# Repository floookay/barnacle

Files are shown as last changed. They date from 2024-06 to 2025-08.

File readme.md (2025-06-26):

# barnacle

The barnacle is unibody ortho keyboard with an Alice-like split on the pinky columns, a fixed layout that's compatible with keycap base kits and a modular middle piece.

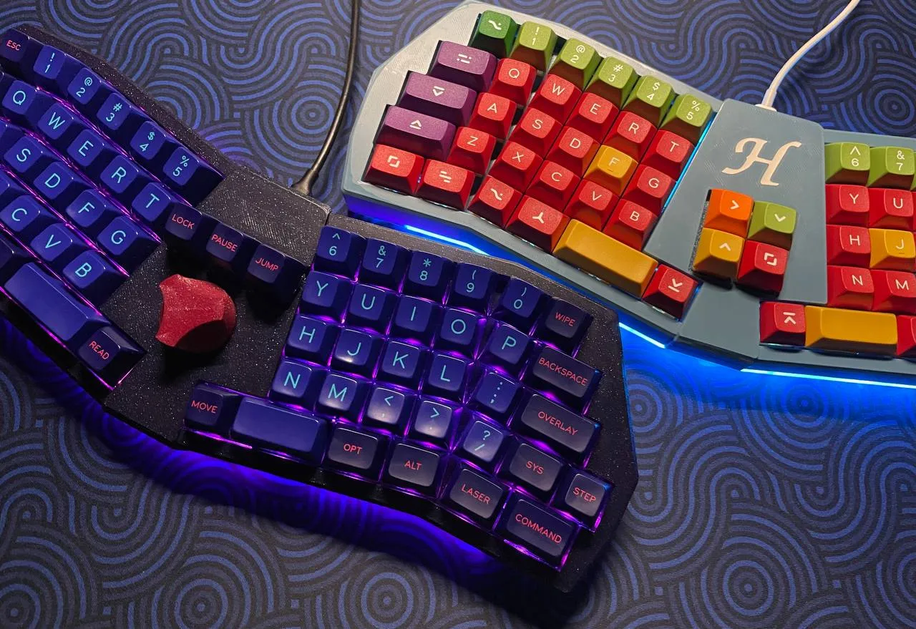
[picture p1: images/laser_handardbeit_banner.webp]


## inspiration

I love the look of the boardrun classic and desperately wanted to get one myself but things happend so that's not likely anymore unfortunately.  
The creativity of designers with colorful keycap designs and interesting keyboard designs got me hooked with the hobby. I bought a bunch of keycap sets over the years that I don't use anymore since I switched to ortho/colstagger keyboards a couple of years ago, because the different asymmetrical key sizes of standard keyboards make it difficult. I don't like the layout or the asthetics of most keyboard designs that are trying to work around this issue. That's why I created the barnacle.

## design goals

- 5x6 unibody ortho keyboard
- base kit compatibility
- 3d printable on 220mm build plates
- symmetric design (amap)
- outer thumb keys next to space bars
- easily expandable later on
- no stabilizers

## layout

The main layout you use to type is fixed but the different cores offer some variety. The default keymap is based on my Sol 3 keymap but you can modify it in QMK of course.

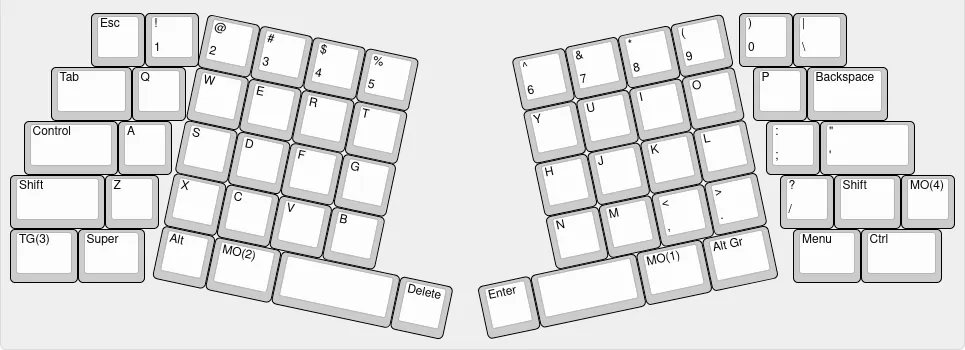
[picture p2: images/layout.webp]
layout


The base layout is pretty much compatible with every base kit. These are the keys you could look out for beforehand as they are sometimes missing:
- a second R3 1.75u key (capslock/control)
- if ISO is omitted and the bottom row is another profile than the row above: a 1.25u shift key. If they are the same profile you can use the 7th 1.25u mod key
- 2u and 2.25u space bars, alternativly you can use shift keys

> [!TIP]
> Some 40s kits have accent colored R3 1.75u enter keys so thats something you could look out for if you like accent keys.

## pcb

The barnacle uses a two part pcb design which are connected via hotswap sockets:  
- shell pcb
- core pcb in different variations

It uses the [0xCB Helios](https://keeb.supply/products/0xcb-helios) as its controller. It's an affordable open-source pro-micro-compatible RP2040 controller with ESD protection and additional pins and features.

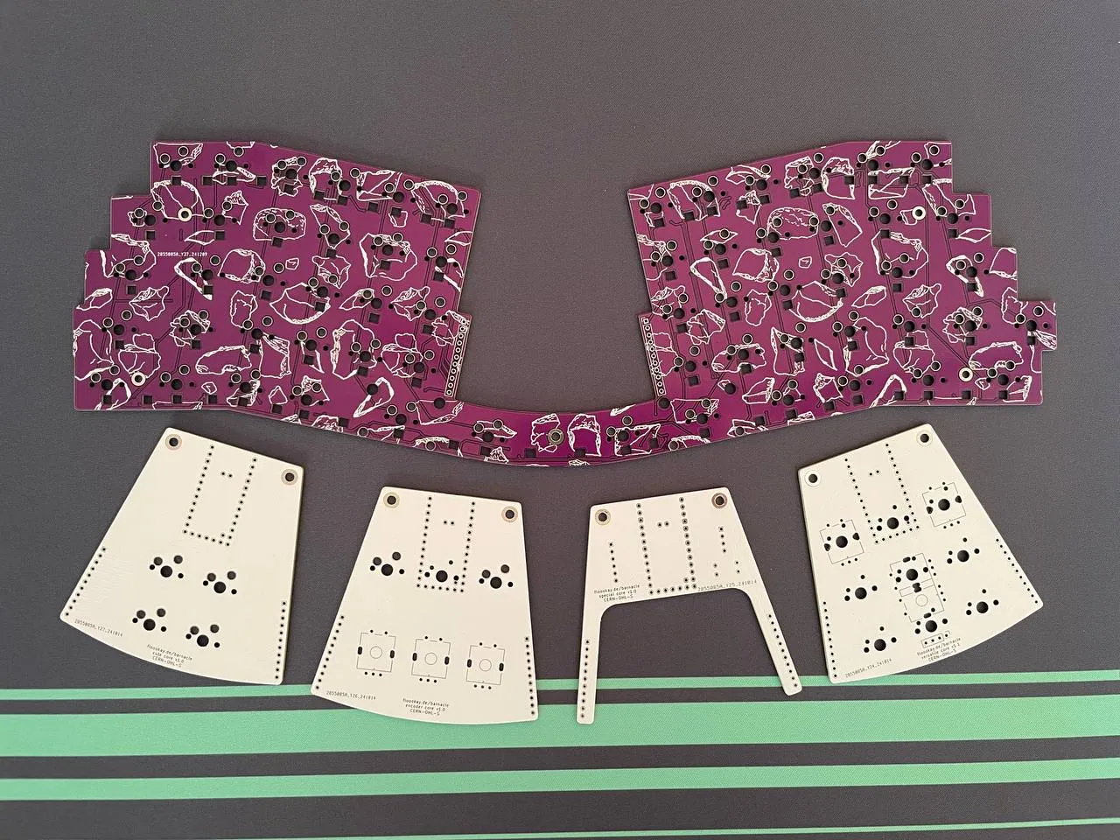
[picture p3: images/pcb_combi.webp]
pcb


> [!NOTE]
> See [pcb readme](./pcb/readme.md) for detailed information about the pcb design.

## case

- 3mm acrylic bottom
- 5 degree typing angle
- designed for 3d printing
- sandwich mount
- exchangable core pieces

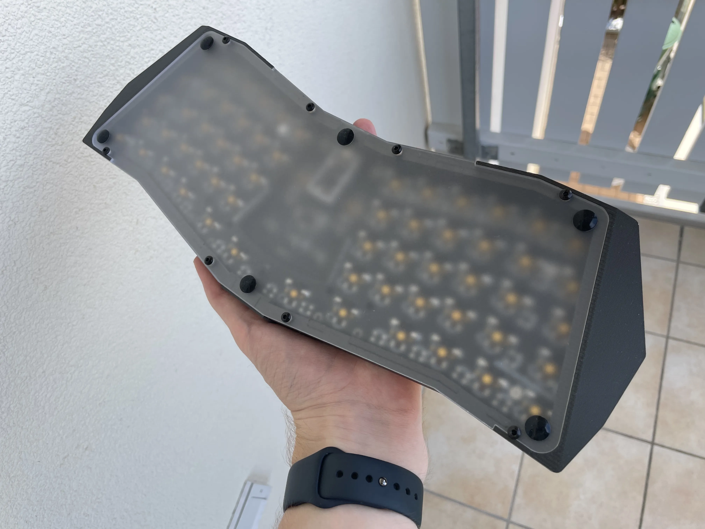
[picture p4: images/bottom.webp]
bottom

<details>
<summary>side and back pictures</summary>

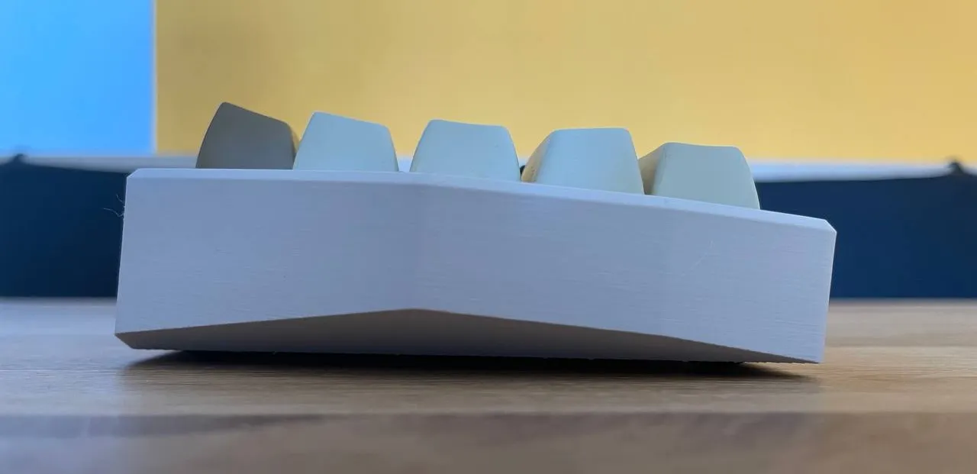
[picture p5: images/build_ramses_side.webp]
side profile

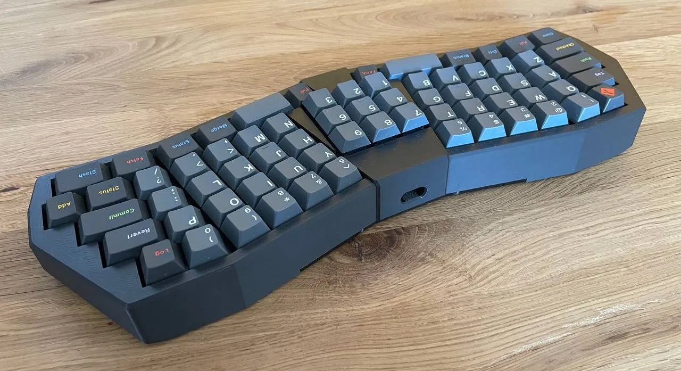
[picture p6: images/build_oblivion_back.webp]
backside

</details>

> [!NOTE]
> See [case readme](./case/readme.md) for detailed information about the case design.

## firmware

This keyboard is powered by QMK: <https://github.com/floookay/qmk_firmware/tree/barnacle/keyboards/barnacle> (not yet in main branch)

I also uploaded a firmware for vial as well as the json in the firmware folder.

## bom and assembly

For the bill of materials and assembly instructions see [here](./build_guide.md).

## pictures

<details>
<summary>encoder core, SA Ramses, Novelkeys x Kailh Cream, printed with AzureFilm PLA Matte Off-White</summary>

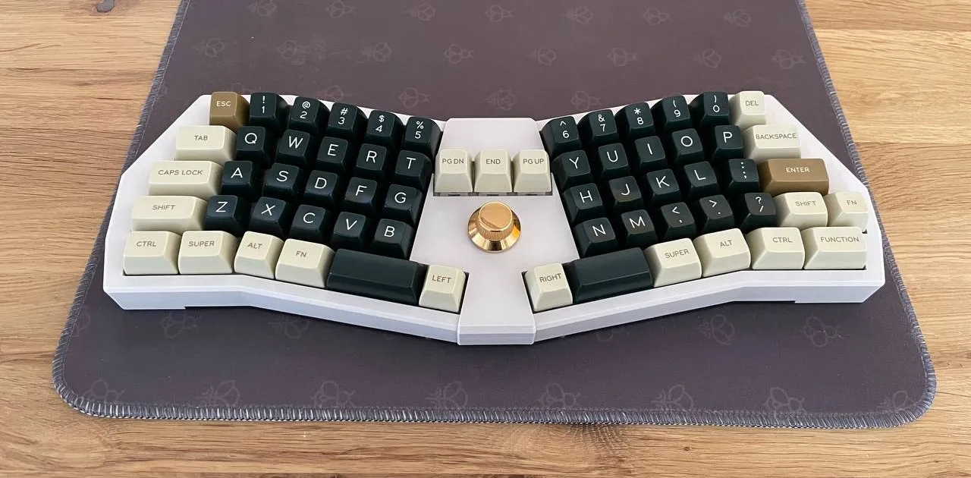
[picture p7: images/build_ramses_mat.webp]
  
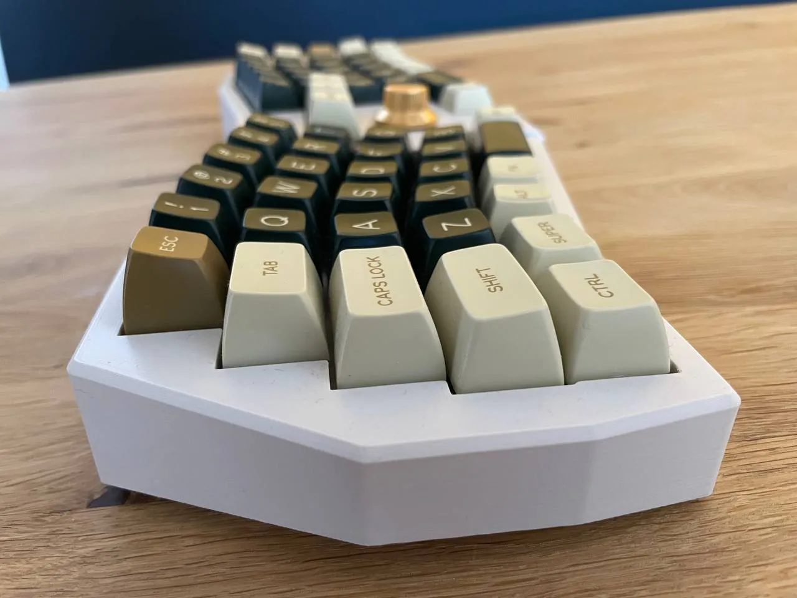
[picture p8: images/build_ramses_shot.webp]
  
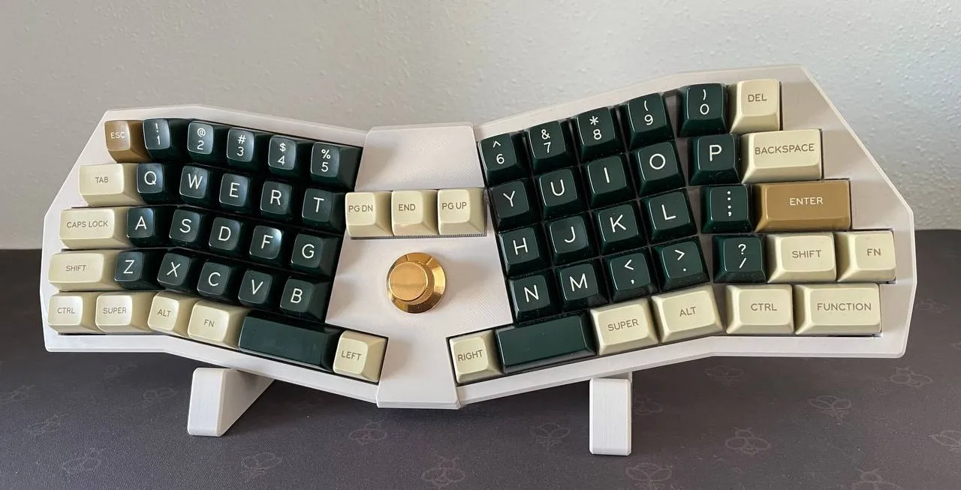
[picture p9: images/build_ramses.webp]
  
</details>

<details>
<summary>cute core, DSS Handarbeit, Gateron EF Curry, printed with RecylingFabrik rPLA flaches Gewässer</summary>

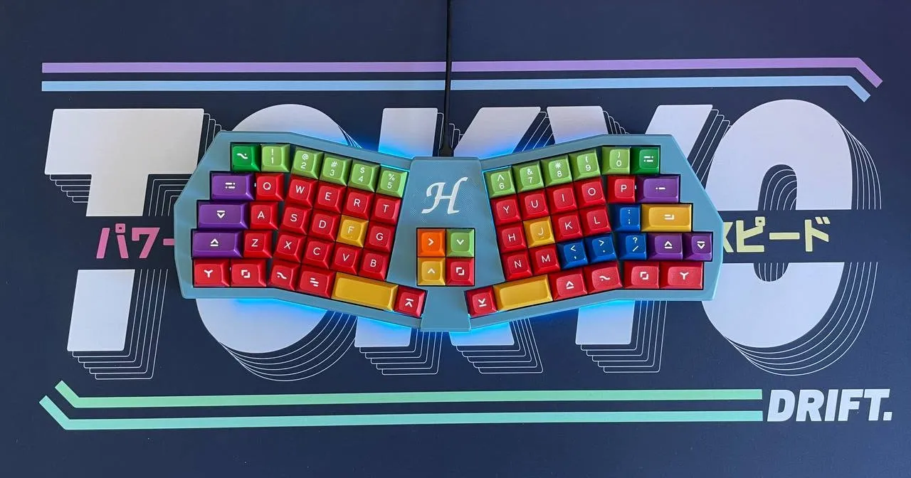
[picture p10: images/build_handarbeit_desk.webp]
  
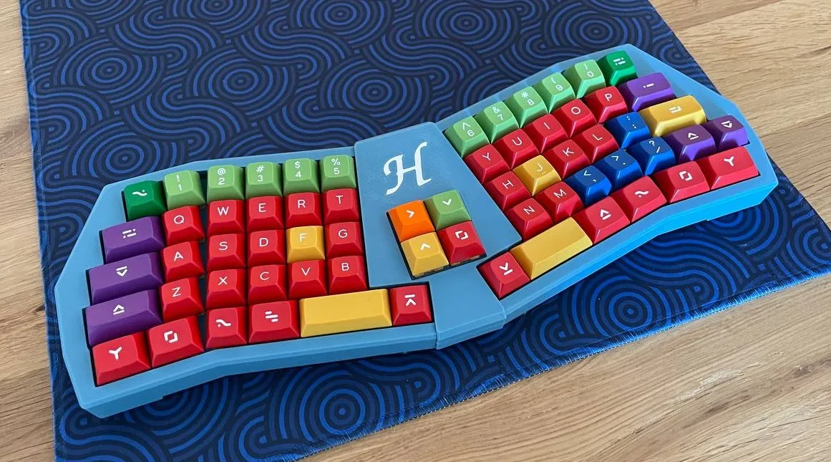
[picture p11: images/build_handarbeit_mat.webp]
  
</details>

<details>
<summary>versatile core with a 1.3" oled screen, GMK Dracula, Gateron Black Silent Inks, printed with Prusament PLA Galaxy Black</summary>

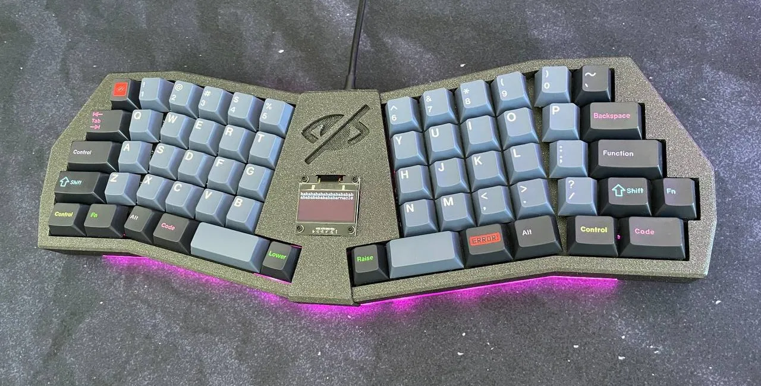
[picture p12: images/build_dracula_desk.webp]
  
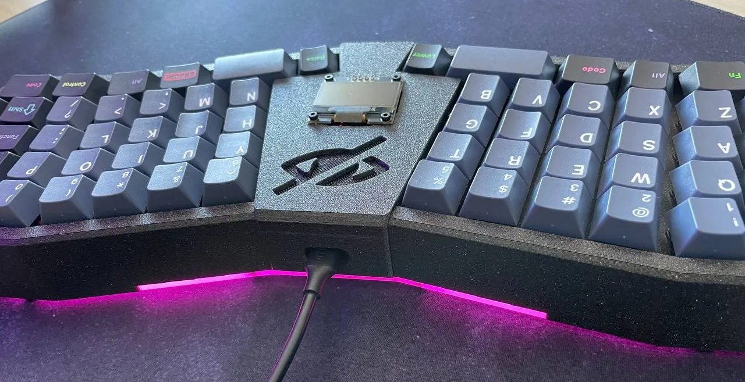
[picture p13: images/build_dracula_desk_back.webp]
  
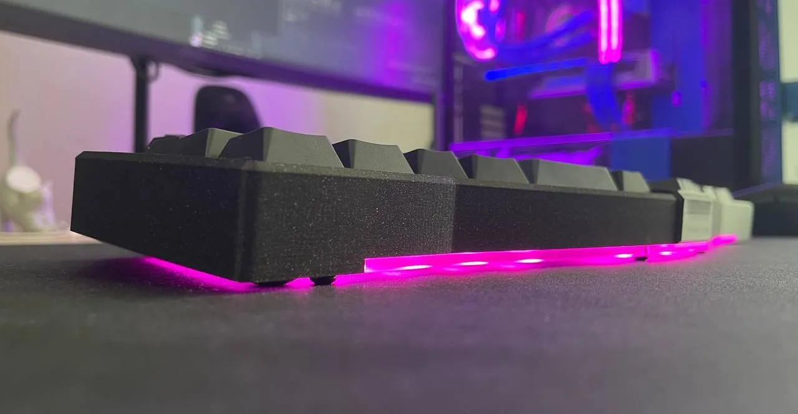
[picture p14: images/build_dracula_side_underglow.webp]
  
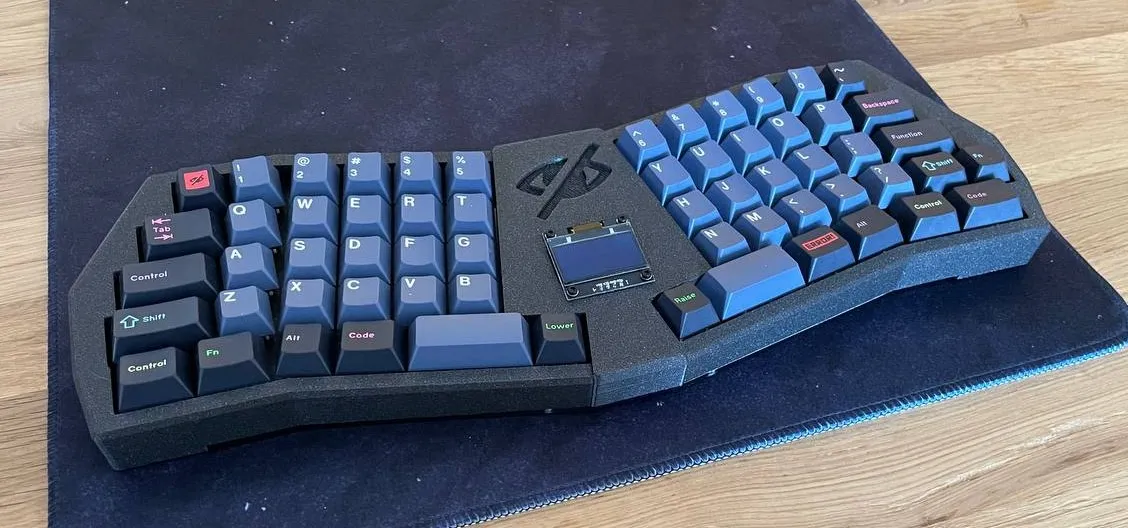
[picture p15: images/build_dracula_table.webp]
  
</details>

<details>
<summary>versatile core encoder, MT3 Serika, Trash Linears, printed with Sunlu PLA Black matte</summary>

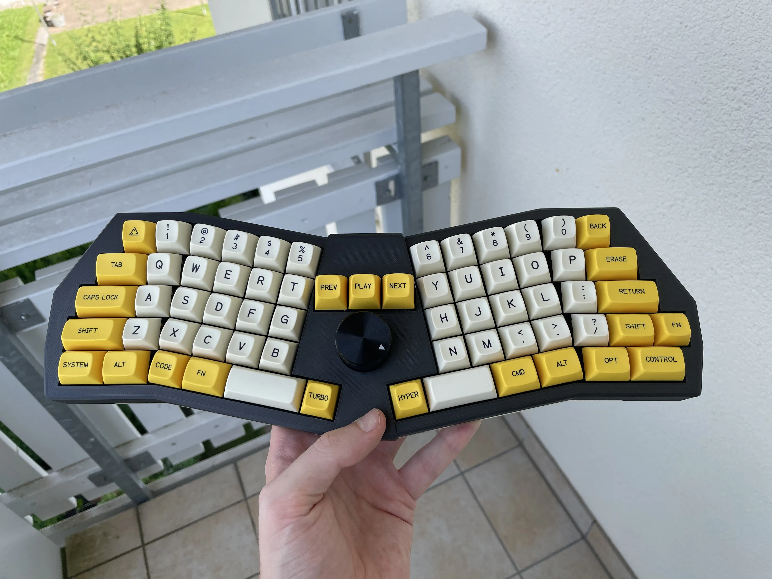
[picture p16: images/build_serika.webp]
  
</details>

<details>
<summary>encoder core, SA Laser, Gateron Black Silent Inks, printed with Polymaker PolyLite PLA Galaxy Dark Blue</summary>

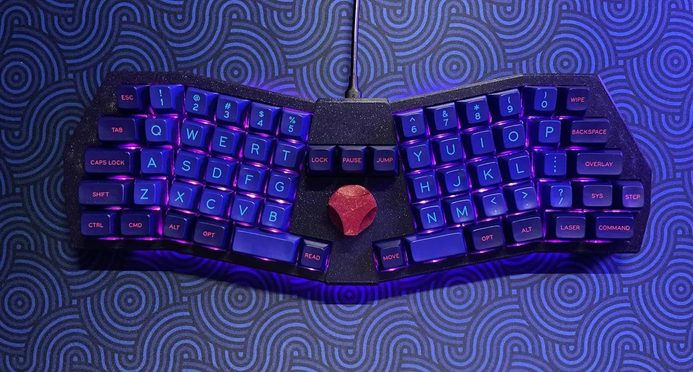
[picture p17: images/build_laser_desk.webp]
  
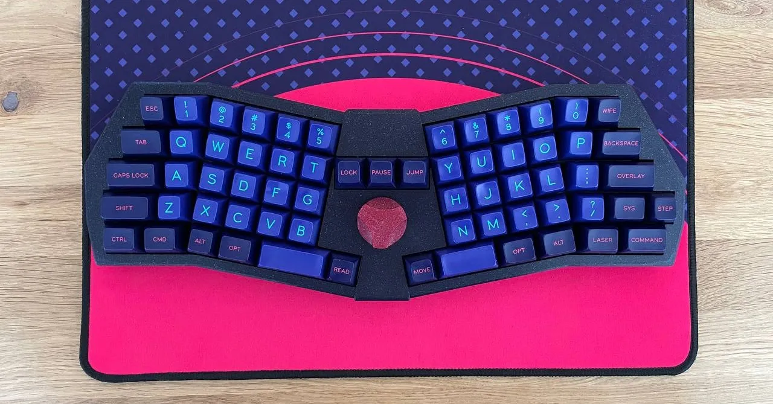
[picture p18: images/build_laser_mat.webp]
  
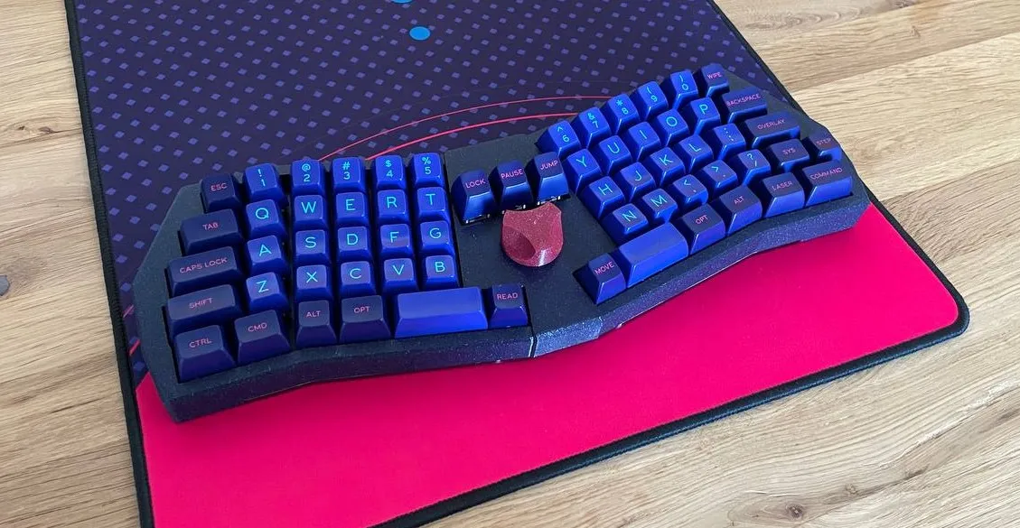
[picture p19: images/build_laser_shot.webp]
  
</details>

<details>
<summary>versatile core, GMK Foundation, MMD Holy Panda, printed with AzureFilm PLA Matte Off-White</summary>

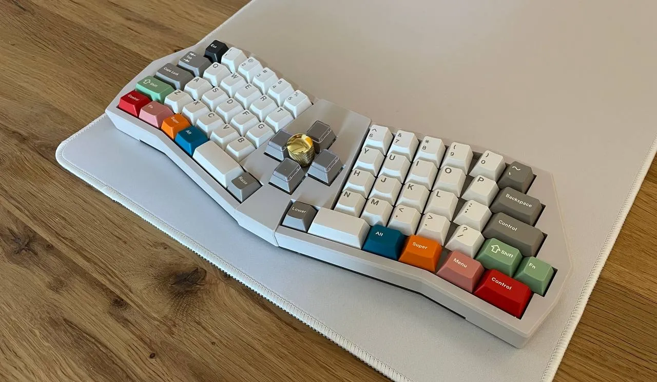
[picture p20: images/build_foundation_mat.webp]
  
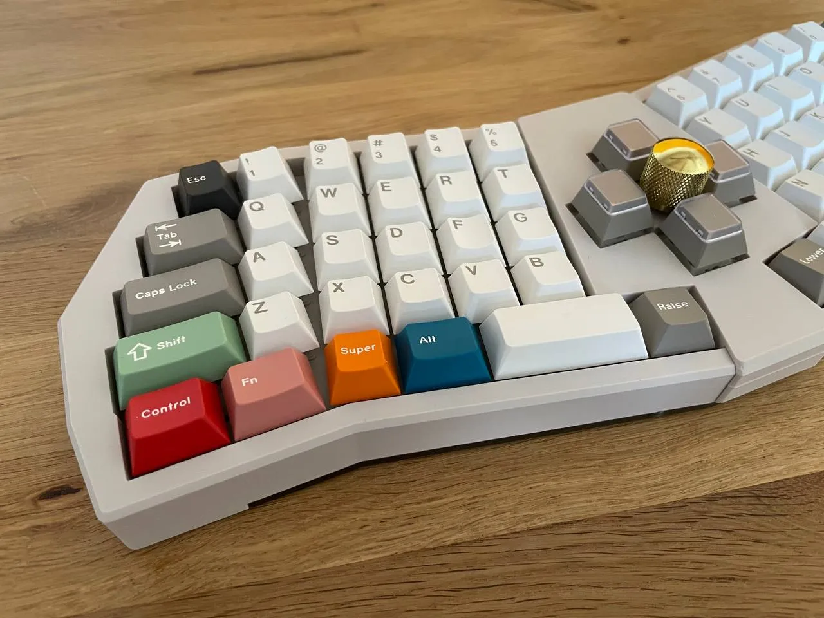
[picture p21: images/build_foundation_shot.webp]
  
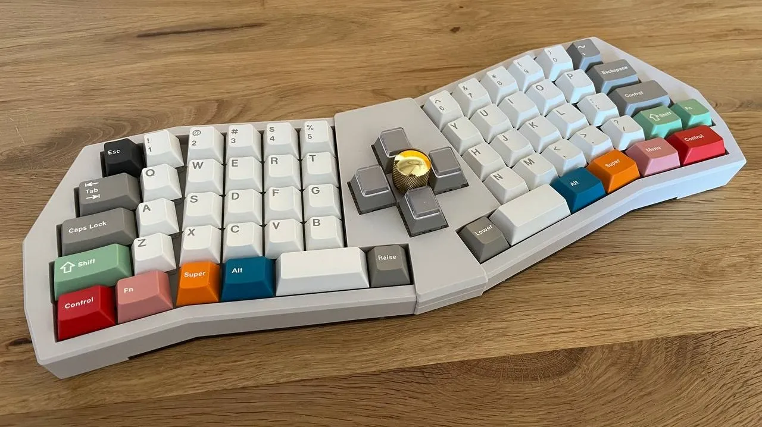
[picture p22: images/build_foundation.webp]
  
</details>

<details>
<summary>versatile core numpad, GMK Oblivion, Gateron 8008 Inks, printed with RecylingFabrik rPLA Schimmernde Nacht</summary>

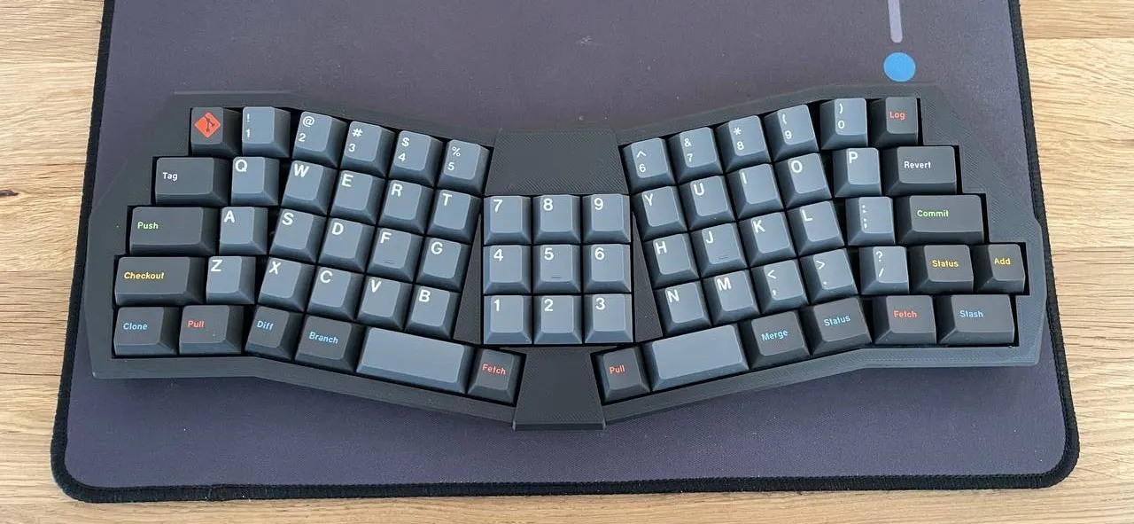
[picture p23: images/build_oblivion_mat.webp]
  
barnacle  
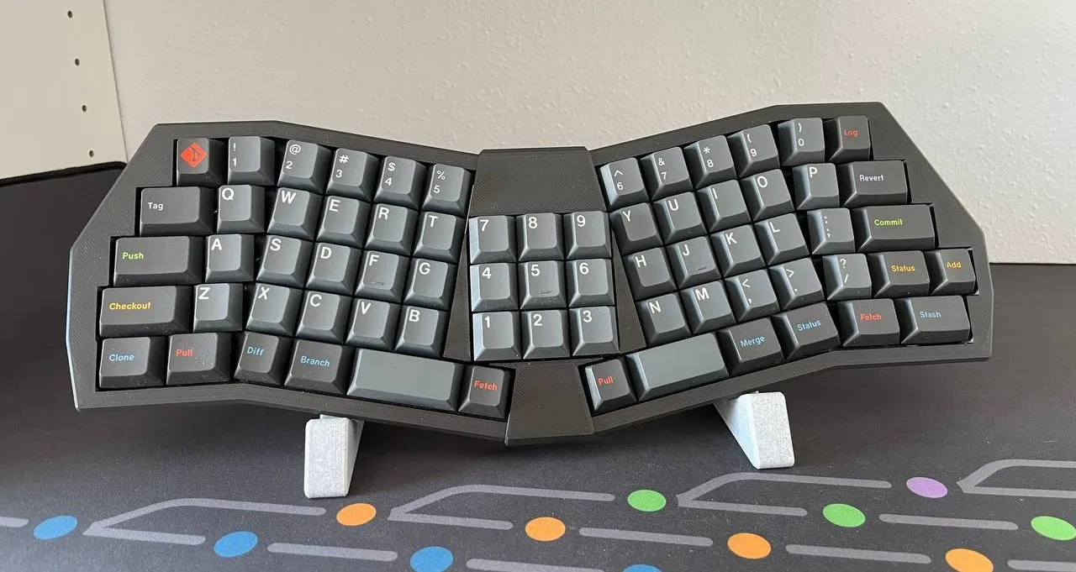
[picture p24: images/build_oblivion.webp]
  
</details>

## acknowledgements

Huge thank you to ebastler and MarvFPV for the awesome [marbastlib](https://github.com/ebastler/marbastlib) library for KiCAD as well as the ClackTales community for their support.

Thanks for reading and feel free to reach out to me or create issues or PRs if you have any questions or things to improve upon.

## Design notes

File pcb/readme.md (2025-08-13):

# pcb

## shell pcb

The shell has a fixed layout with hotswap sockets as well as RGB underglow und per key RBG leds.

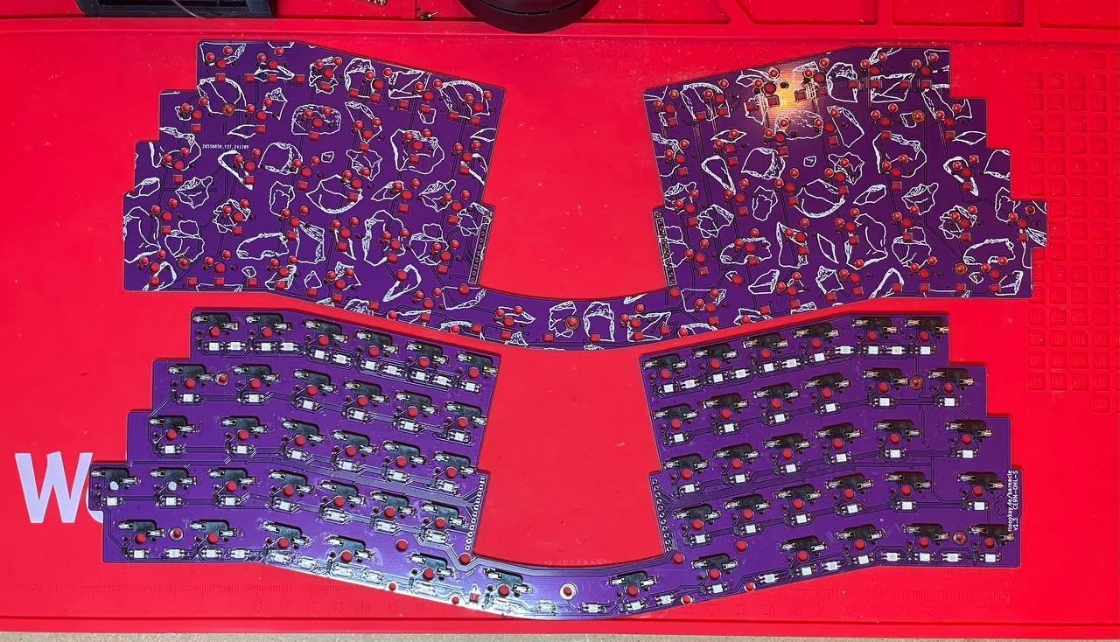
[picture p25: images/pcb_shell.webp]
shell top


## core pcb

You can use any core pcb with a shell. They are smaller than 100mmx100mm so it's relativly cheap to get a small batch made.

> [!NOTE]
> Every core has two jumpers at the top next to the controller. If you want to use RGB leds you will have to bridge either the left or right pads each.
> - Left jumper pad for the input pin: left (marked) for the Helios' pin 25, right for other controllers (D1)
> - Right jumper pad for the power source: left (marked) for raw/5V, right for 3.3V

### versatile core

This is a great starting point if you want to experiment with different layouts and don't care too much about hot swap ability.

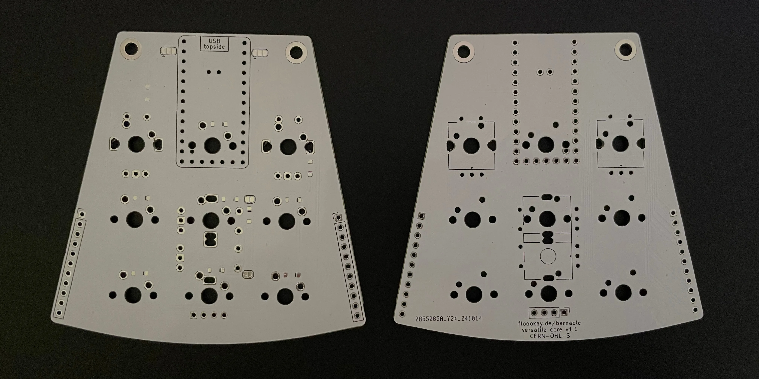
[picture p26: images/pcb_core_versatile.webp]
versatile core


The following configurations are supported:
- 9 keys
- 3 keys and a encoder with a big knob
- 3 keys and a 0.96"/1.3" OLED screen
- 2 small encoders, 1 key and a 0.96" OLED screen
- a central encoder with the biggest knob

> [!NOTE]
> There are two additional jumpers on this pcb. These are used so the GND pad of the encoder isn't connected to a column. If you want to use the adjacent key you'll have to close it.

### encoder core

This core has three top keys and a encoder beneath like the versatile core but with hot swap sockets.

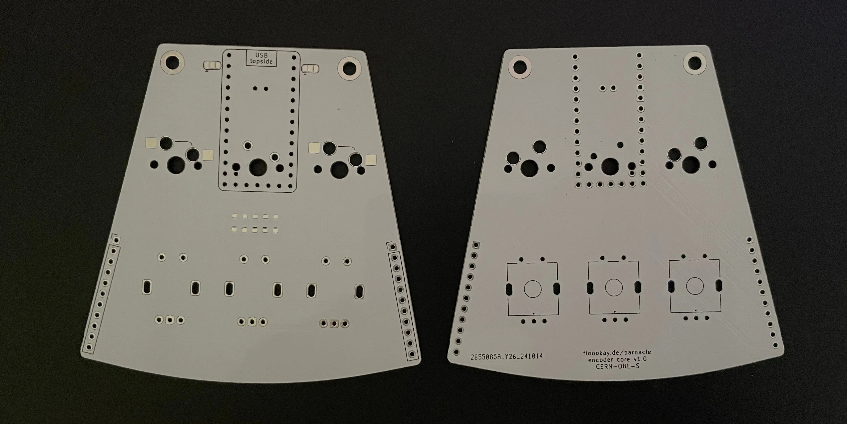
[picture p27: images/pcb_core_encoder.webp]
encoder core


### special core

This core exposes I2C and SPI pins and has a large cutout for mounting a trackball, trackpad or large oled to the core case (WIP).

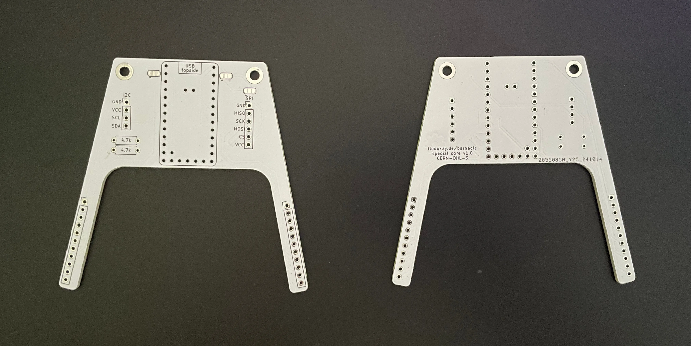
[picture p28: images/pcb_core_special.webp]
special core


### cute core

This core has centered 2x2 grid of keys with hot swap sockets.

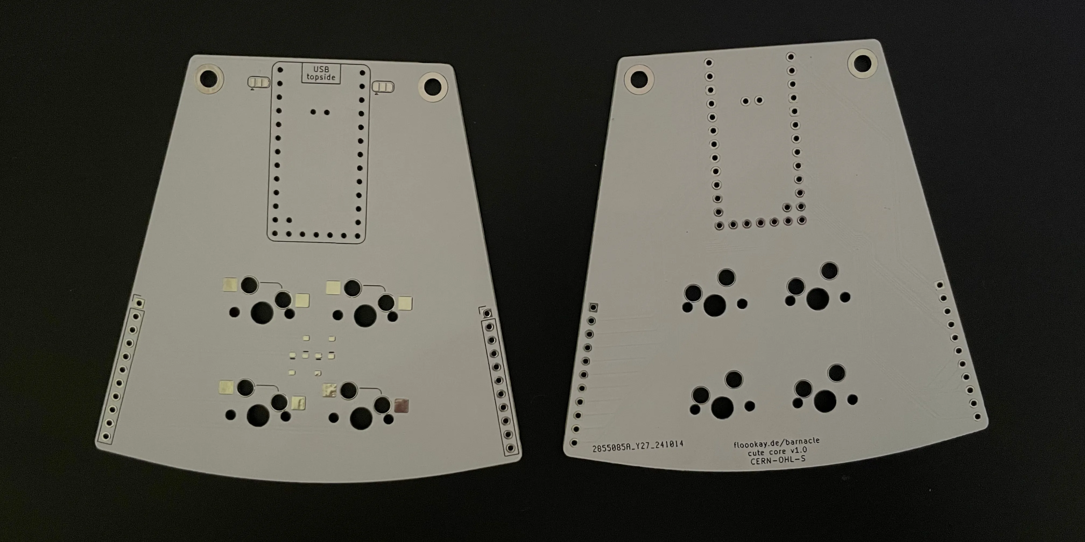
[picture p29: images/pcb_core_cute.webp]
cute core


### numpad core

This core has a 3x3 grid of keys with hot swap sockets (when possible) and an additional 0 key that can be snapped off.

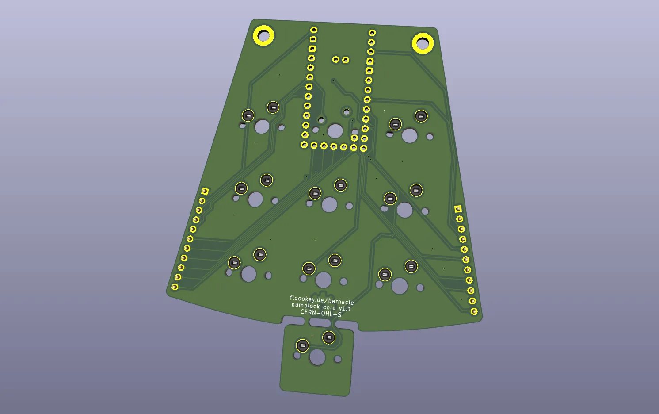
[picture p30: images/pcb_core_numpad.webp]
numpad core


### _template/ directory

The `_template/` directory contains the basic configuration if you want to create your own core pcb.

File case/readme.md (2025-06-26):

# case

- 3mm acrylic bottom
- 5 degree typing angle
- designed for 3d printing
- sandwich type mount
- exchangable core pieces

The case files were designed with FreeCAD 0.21.2

## main

You'll have to split the shell piece into two pieces in the slicer at the groove (the bridge should not be printed). It's not important if the cut removes a little bit of material above the groove. This will be hidden later.

The plate is sandwiched in between the shell and fixer pieces. You can customize the spreadsheet in the FreeCAD file if you are having troubles with the tolerances (it's a tight fit).

The acrylic bottom connects the 3d printed case parts together.

> [!WARNING]  
> Please note that the acrylic bottom is not symmetrical! You may want to flip the file if you order the plate with a certain surface finish. The edge on the right side is longer.

## core

### versatile core

This is a great starting point if you want to experiment with different layouts and don't care too much about hot swap ability.

The following configurations are supported:
- 9 keys
- 3 keys and a encoder with a big knob
- 3 keys and a 0.96"/1.3" OLED screen
- 2 small encoders, 1 key and a 0.96" OLED screen
- a central encoder with the biggest knob

I added a couple of printable cores possible with the versatile core pcb but to get

### encoder core

This core has three top keys and a encoder beneath like the versatile core but with hot swap sockets. Alternatively you can install an encoder on the left and a second one on the right.

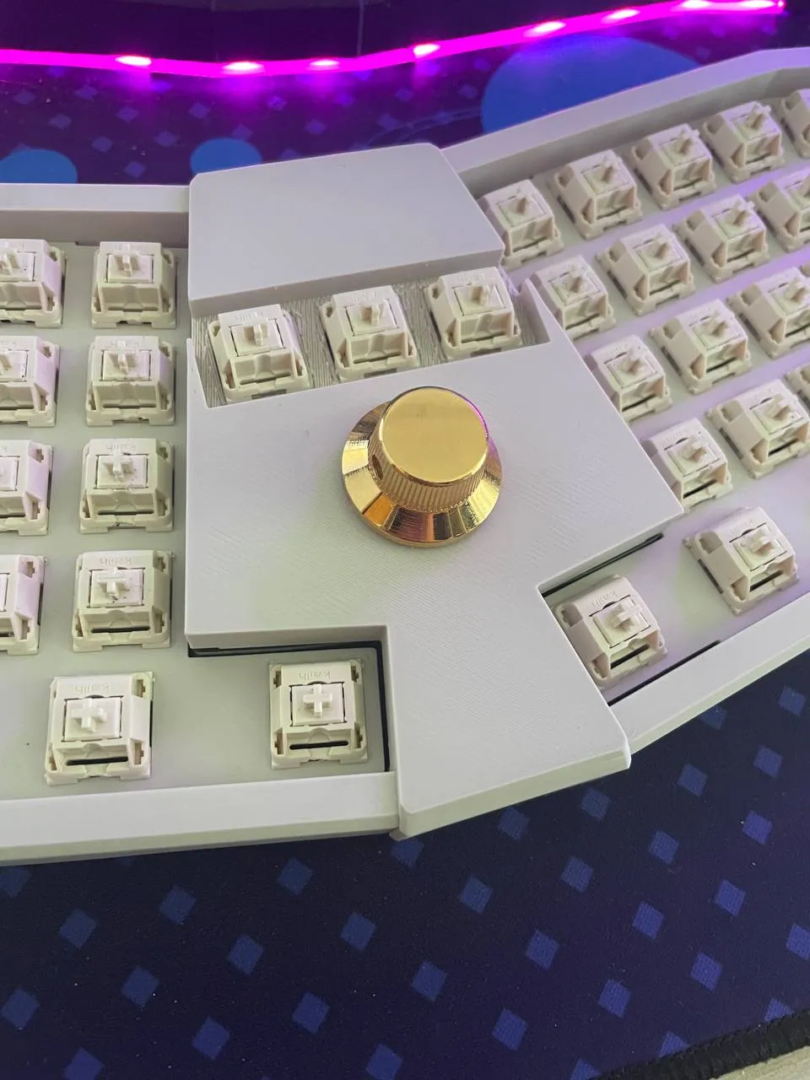
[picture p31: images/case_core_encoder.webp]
encoder core


### special core

This core is intended for fun stuff like a trackball or similiar but I haven't worked on that yet.

### cute core

This is just a simple core with 4 centered keys with hot swap.

> [!TIP]
> You can add text or graphics in the slicer

### wood core

This core is also a work in progress. The plan is to add a wooden window piece.

## the „weight“

This is a 3d printable weight you can print with 100% infill to dampen the sound and make the build by about 200g heavier. It's not fixated or anything it just sits above the acrylic. You can split it in half for printing on usual sized print beds.

## printer settings

- 0.4mm nozzle
- 0.2mm layer height

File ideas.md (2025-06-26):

# ideas and stuff I may or may not add in the future

## pcb

- [ ] **bluetooth core** with a nice!nano and without RGB (maybe with a safety cover toggle switch or sth)
- [x] **trackball core** with PMW3360 sensor (&rarr; special core)
- [x] **trackpad core** with a 40mm GlidePoint Cirque Trackpad (&rarr; special core)
- [ ] **oled core** with a large (colored?) OLED screen
- [ ] **lumberjack core** with a window and an integrated controller
- [ ] **rgb core** with a window and a rgb matrix
- [ ] **audio core** with a speaker/beeper

## case

- [ ] **brick core** with brick plate on top
- [ ] **wood core** with a cutout wooden window piece
- [ ] **gridfinity core** with a spot for a gridfinity bin
- [ ] **phone core** with a holder for (small) phones, maybe with a magsafe charger
- [ ] **change core** with a tray for coins and stuff
- [ ] **pen core** with a hole that fits a pen

## firmware

- [ ] **ZMK support** with the bluetooth core
- [x] **vial support** with 3x3 core, encoder and rgb support

## other

I'd love to do a 40% version at some point but that would be a complete rework. Maybe someday in the future.

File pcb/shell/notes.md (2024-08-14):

# notes

## 1x11 connector
square pad 12mm left/right to the center of the inner r3 switch

## underglow leds
exactly 10.525mm (19.05/2+1mm) from the center of the per key rgb footprint (diode side)

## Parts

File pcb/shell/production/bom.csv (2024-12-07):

Designator | Footprint | Quantity | Value | LCSC Part #
D1, D10, D11, D12, D13, D14, D15, D16, D17, D18, D19, D2, D20, D21, D22, D23, D24, D25, D26, D27, D28, D29, D3, D30, D31, D32, D33, D34, D35, D36, D37, D38, D39, D4, D40, D41, D42, D43, D44, D45, D46, D47, D48, D49, D5, D50, D51, D52, D53, D54, D55, D56, D57, D58, D59, D6, D60, D61, D7, D8, D9 | D_SOD-123-minimal | 61 | D | C115103
J1, J2 | PinHeader_1x11_P2.54mm_Vertical | 2 | Conn_01x11
LED1, LED10, LED11, LED12, LED2, LED25, LED26, LED27, LED28, LED29, LED3, LED30, LED31, LED32, LED33, LED34, LED35, LED36, LED4, LED5, LED50, LED51, LED52, LED53, LED54, LED55, LED56, LED57, LED58, LED59, LED6, LED60, LED61, LED7, LED8, LED9 | LED_MX_6028R-ROT | 36 | LED | C5149201
LED13, LED14, LED15, LED16, LED17, LED18, LED19, LED20, LED21, LED22, LED23, LED24, LED37, LED38, LED39, LED40, LED41, LED42, LED43, LED44, LED45, LED46, LED47, LED48, LED49 | LED_MX_6028R | 25 | LED | C5149201
MX1, MX10, MX11, MX12, MX13, MX14, MX15, MX16, MX17, MX18, MX19, MX2, MX20, MX21, MX22, MX23, MX24, MX25, MX26, MX27, MX28, MX29, MX3, MX30, MX31, MX32, MX33, MX34, MX35, MX36, MX37, MX38, MX39, MX4, MX40, MX41, MX42, MX43, MX44, MX45, MX46, MX47, MX48, MX49, MX5, MX50, MX51, MX52, MX53, MX54, MX55, MX56, MX57, MX58, MX59, MX6, MX60, MX61, MX7, MX8, MX9 | SW_MX_HS_S_CPG151101S11_1u | 61 | MX_SW_HS
UG1, UG10, UG11, UG12, UG13, UG14, UG15, UG16, UG17, UG18, UG19, UG2, UG20, UG21, UG22, UG3, UG4, UG5, UG6, UG7, UG8, UG9 | sk6812 mini-e towards-facing | 22 | LED

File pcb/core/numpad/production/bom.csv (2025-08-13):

Designator | Footprint | Quantity | Value | LCSC Part #
D1, D10, D2, D3, D4, D5, D6, D7, D8, D9 | D_SOD-123-minimal | 10 | D
J1, J2 | PinHeader_1x11_P2.54mm_Vertical | 2 | Conn_01x11
SW1, SW10, SW3, SW4, SW5, SW6, SW7, SW8, SW9 | SW_MX_HS_S_CPG151101S11_1u | 9 | SW_Push_45deg
SW2 | SW_MX_1u | 1 | SW_Push_45deg

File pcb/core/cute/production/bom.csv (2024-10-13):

Designator | Footprint | Quantity | Value | LCSC Part #
D5, D6, D8, D9 | D_SOD-123-minimal | 4 | D
J1, J2 | PinHeader_1x11_P2.54mm_Vertical | 2 | Conn_01x11
SW5, SW6, SW8, SW9 | SW_MX_HS_S_CPG151101S11_1u | 4 | SW_Push_45deg

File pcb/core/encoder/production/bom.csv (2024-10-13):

Designator | Footprint | Quantity | Value | LCSC Part #
D1, D10, D2, D3, D4 | D_SOD-123-minimal | 5 | D
J1, J2 | PinHeader_1x11_P2.54mm_Vertical | 2 | Conn_01x11
SW1, SW3 | SW_MX_HS_S_CPG151101S11_1u | 2 | SW_Push_45deg
SW11, SW4, SW5 | ROT_Alps_EC11E-Switch | 3 | RotaryEncoder_Switch
SW2 | SW_MX_1u | 1 | SW_Push_45deg

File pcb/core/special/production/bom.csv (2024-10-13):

Designator | Footprint | Quantity | Value | LCSC Part #
J1, J2 | PinHeader_1x11_P2.54mm_Vertical | 2 | Conn_01x11
J3 | PinHeader_1x04_P2.54mm_Vertical | 1 | I2C
J4 | PinHeader_1x06_P2.54mm_Vertical | 1 | SPI
R1, R2 | R_Axial_DIN0207_L6.3mm_D2.5mm_P7.62mm_Horizontal | 2 | 4.7k | C269746

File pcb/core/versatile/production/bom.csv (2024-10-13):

Designator | Footprint | Quantity | Value | LCSC Part #
D1, D10, D2, D3, D4, D5, D6, D7, D8, D9 | D_SOD-123-minimal | 10 | D
J1, J2 | PinHeader_1x11_P2.54mm_Vertical | 2 | Conn_01x11
J3 | PinHeader_1x04_P2.54mm_Vertical | 1 | Conn_01x04
SW1, SW2, SW3, SW4, SW5, SW6, SW7, SW8, SW9 | SW_MX_1u | 9 | SW_Push_45deg
SW10, SW11, SW12, SW13 | ROT_Alps_EC11E-Switch | 4 | RotaryEncoder_Switch

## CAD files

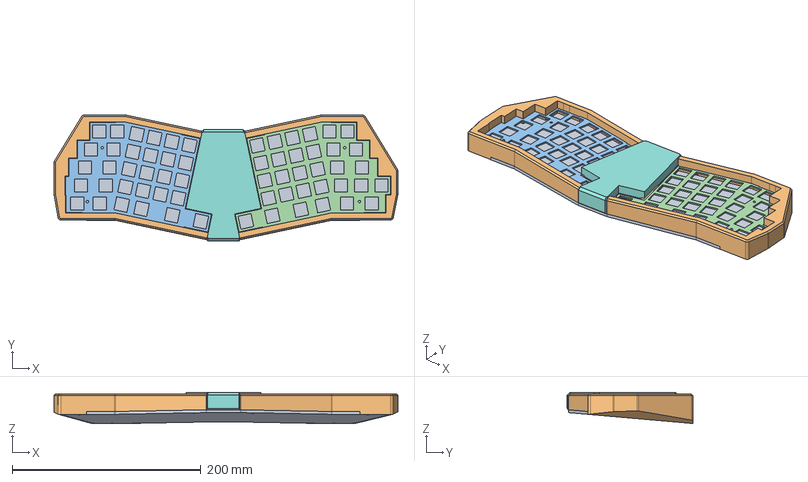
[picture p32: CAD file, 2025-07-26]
case/barnacle.FCStd
364.8 x 133.4 x 32.9 mm
pcb
case
plate_left
plate_right
plate_fixer_top
plate_fixer_bottom
pcb_core
case_core
bottom_plate

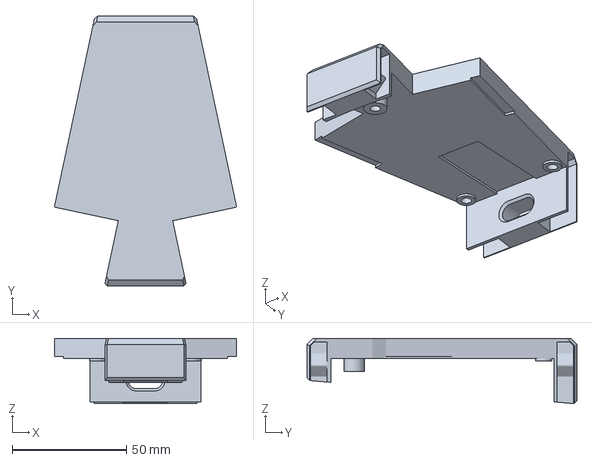
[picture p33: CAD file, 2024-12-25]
case/core/barnacle-case-core_blank.3mf
79.7 x 118.0 x 28.4 mm

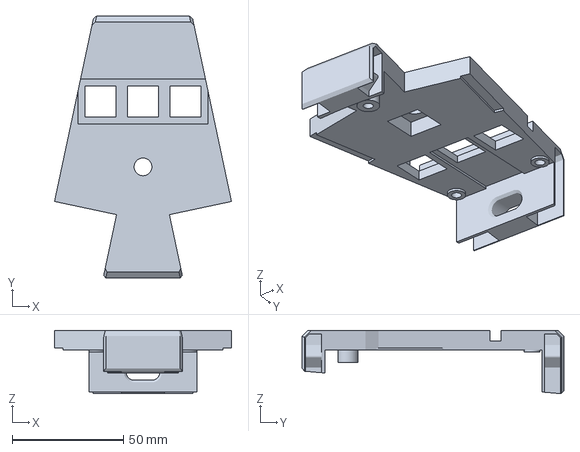
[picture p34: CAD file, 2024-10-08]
case/core/encoder/barnacle-case_core_encoder.3mf
79.7 x 118.0 x 28.4 mm

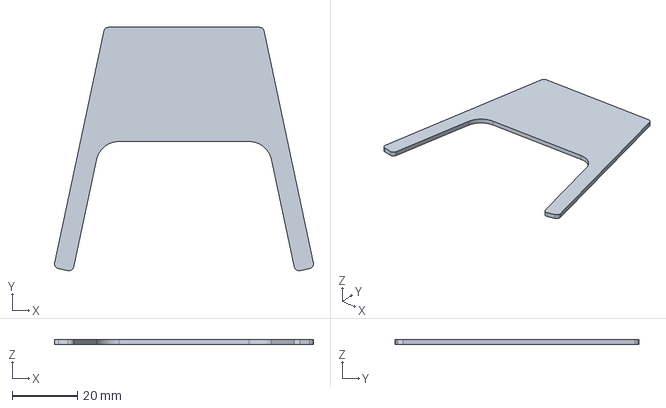
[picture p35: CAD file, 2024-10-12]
case/core/special/barnacle-special_core.FCStd
79.3 x 74.6 x 1.60 mm

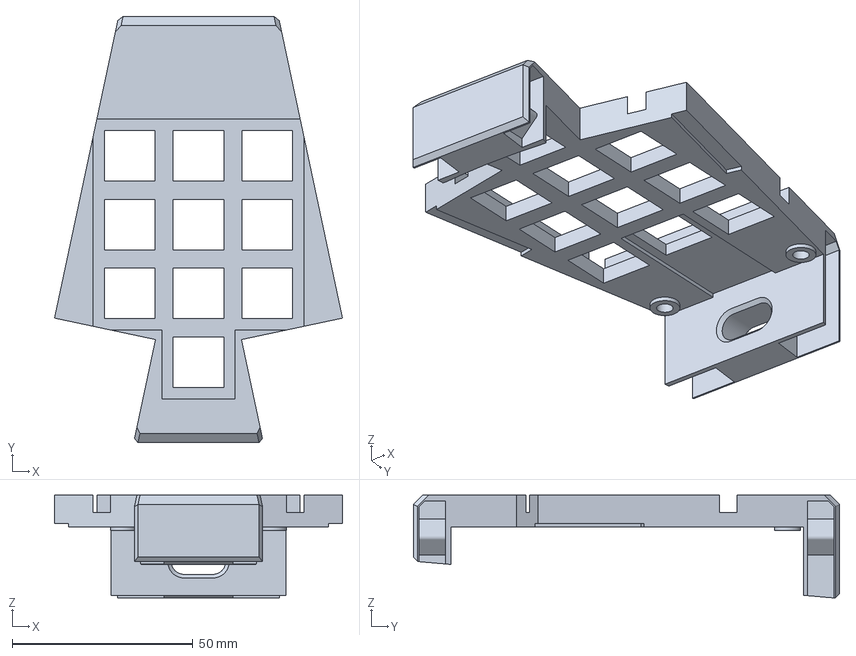
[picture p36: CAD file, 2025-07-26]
case/core/versatile/barnacle-case_core_3x3+1.3mf
79.7 x 118.0 x 28.4 mm

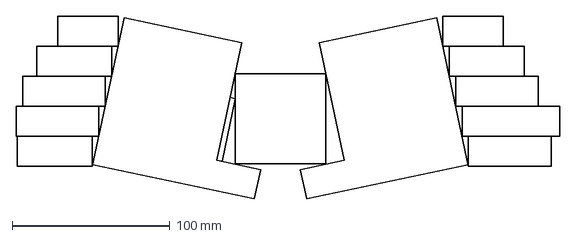
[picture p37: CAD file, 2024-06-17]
pcb/barnacle-pcb-comments.dxf
344.8 x 116.0 mm

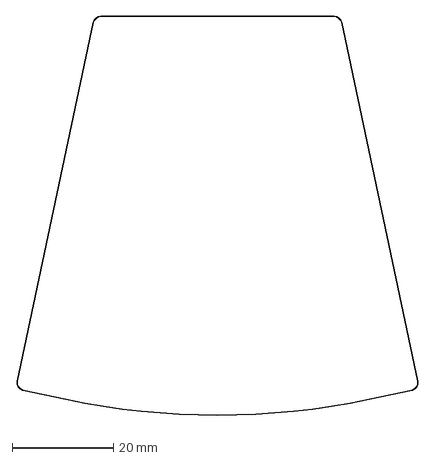
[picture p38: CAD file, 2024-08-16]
pcb/core/barnacle-pcb_core.dxf
79.6 x 79.9 mm

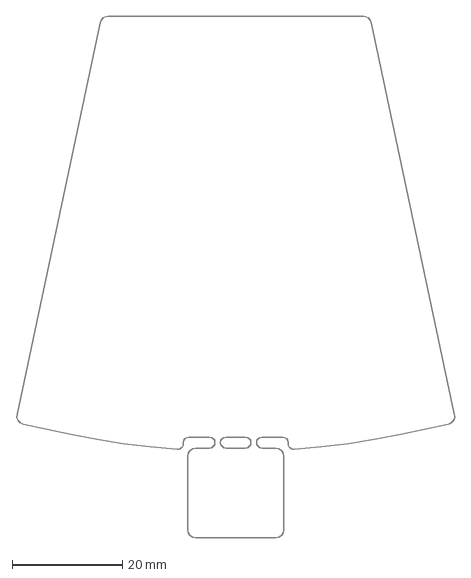
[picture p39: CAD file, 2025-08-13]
pcb/core/numpad/barnacle-pcb_core_numpad.dxf
79.5 x 94.5 mm

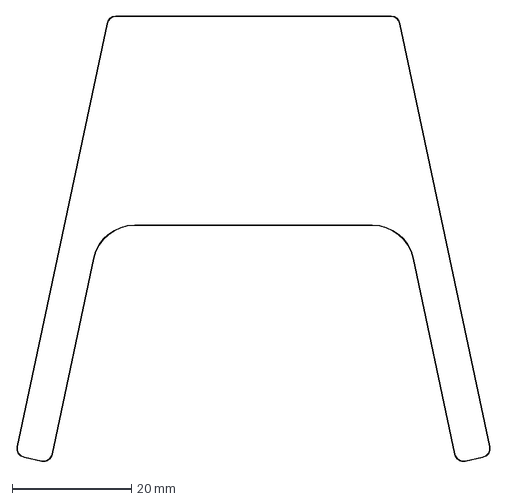
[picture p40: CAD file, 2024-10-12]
pcb/core/special/barnacle-pcb_core_special.dxf
79.6 x 74.6 mm

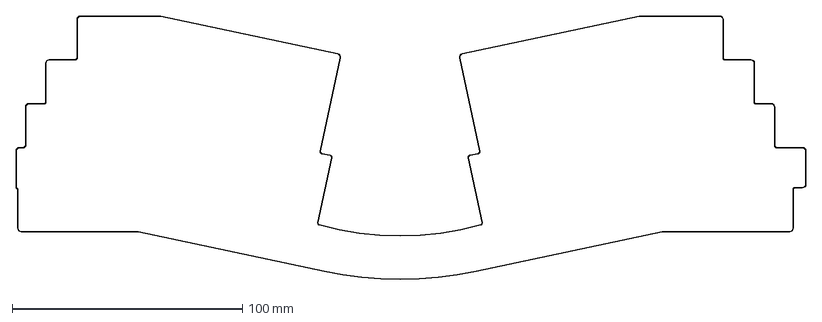
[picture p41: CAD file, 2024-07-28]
pcb/shell/barnacle-pcb.dxf
343.2 x 115.6 mm

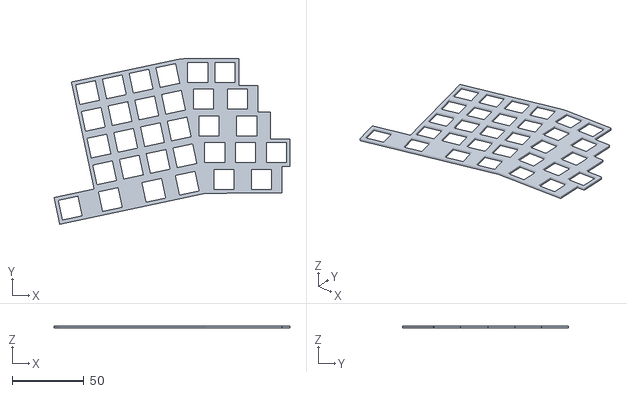
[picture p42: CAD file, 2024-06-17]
prototyping/plate_right_12.stl
164.4 x 115.4 x 1.60

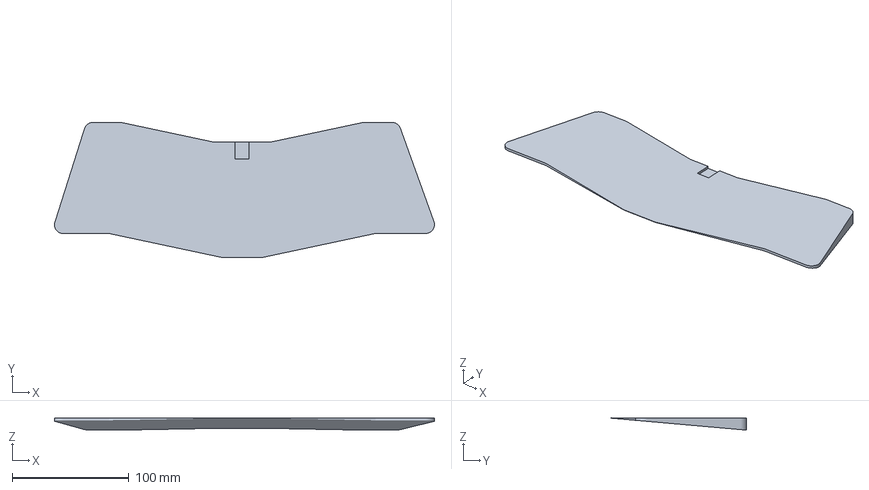
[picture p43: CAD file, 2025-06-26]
case/barnacle-weight.3mf
325.7 x 116.0 x 10.5 mm

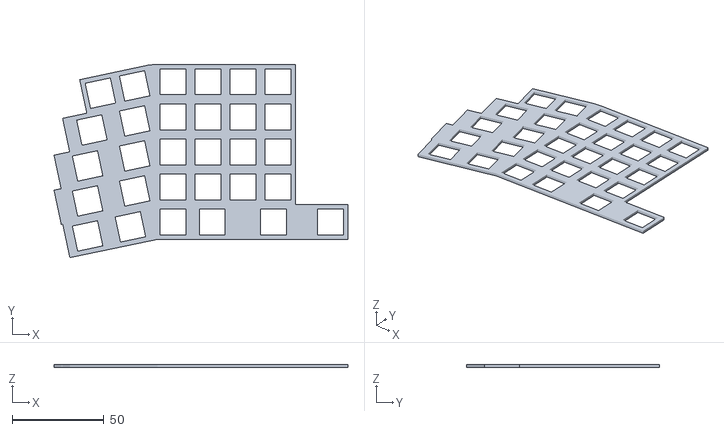
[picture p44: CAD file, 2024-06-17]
prototyping/plate_left_12.stl
160.0 x 105.2 x 1.60

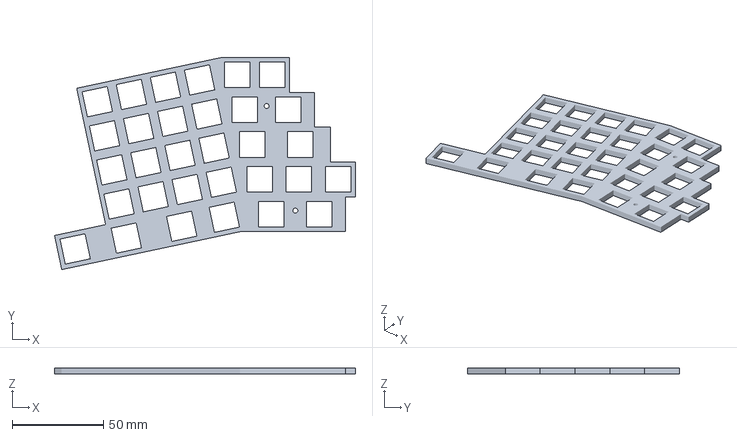
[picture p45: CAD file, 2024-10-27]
case/barnacle-plate_tpu_right.3mf
164.5 x 116.0 x 3.50 mm

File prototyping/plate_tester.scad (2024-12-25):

// please note that the plate produced by this file doesn't have the correct spacing on the pinky columns

KEY_UNIT = 19.05;
KEY_HOLE = 14;
KEY_SPACING = (KEY_UNIT-KEY_HOLE)/2;
ANGLE = 15;
HALF_SPACING = 40;
PLATE_THICKNESS = 1.6;

//plate_right();
plate_left();
//plate_middle();

module plate_middle() {
    translate([-3*KEY_UNIT/2,0,0])
    difference() {
        // 3x3
        cube([3*KEY_UNIT,3*KEY_UNIT,PLATE_THICKNESS]);
        for(i=[0:3]) {
            for(j=[0:3]) {
                translate([KEY_SPACING,KEY_SPACING,-1])
                translate([i*KEY_UNIT,j*KEY_UNIT,0]) cube([KEY_HOLE,KEY_HOLE,PLATE_THICKNESS+2]);
            }
        }
    }
}

module plate_right() {
    translate([5.5*KEY_UNIT*cos(ANGLE)+HALF_SPACING/2,0,0])
    rotate([0,0,ANGLE])
    difference() {
        //// plate
        union() {
            translate([-4*KEY_UNIT,0,0]) union() {
                cube([4*KEY_UNIT,5*KEY_UNIT,PLATE_THICKNESS]);
                translate([-1.5*KEY_UNIT,0,0]) cube([5.5*KEY_UNIT,KEY_UNIT,PLATE_THICKNESS]);
            }
            translate([0,4*KEY_UNIT,0]) hull() {
                translate([-1,0,0]) cube([1,KEY_UNIT,PLATE_THICKNESS]);
                rotate([0,0,-ANGLE]) cube([KEY_UNIT*2,KEY_UNIT,PLATE_THICKNESS]);
            }
            translate([0,3*KEY_UNIT,0]) hull() {
                translate([-1,0,0]) cube([1,KEY_UNIT,PLATE_THICKNESS]);
                rotate([0,0,-ANGLE]) cube([KEY_UNIT*2.5,KEY_UNIT,PLATE_THICKNESS]);
            }
            translate([0,2*KEY_UNIT,0]) hull() {
                translate([-1,0,0]) cube([1,KEY_UNIT,PLATE_THICKNESS]);
                rotate([0,0,-ANGLE]) cube([KEY_UNIT*2.75,KEY_UNIT,PLATE_THICKNESS]);
            }
            translate([0,1*KEY_UNIT,0]) hull() {
                translate([-1,0,0]) cube([1,KEY_UNIT,PLATE_THICKNESS]);
                rotate([0,0,-ANGLE]) cube([KEY_UNIT*3.25,KEY_UNIT,PLATE_THICKNESS]);
            }
            translate([0,0*KEY_UNIT,0]) hull() {
                translate([-1,0,0]) cube([1,KEY_UNIT,PLATE_THICKNESS]);
                rotate([0,0,-ANGLE]) cube([KEY_UNIT*2.75,KEY_UNIT,PLATE_THICKNESS]);
            }
        }
        //// holes
        for(i=[0:3]) {
            for(j=[0:3]) {
                translate([-4*KEY_UNIT,0,0])
                translate([0,KEY_UNIT,0])
                translate([KEY_SPACING,KEY_SPACING,-1])
                translate([i*KEY_UNIT,j*KEY_UNIT,0]) cube([KEY_HOLE,KEY_HOLE,PLATE_THICKNESS+2]);
            }
        }
        translate([-5.5*KEY_UNIT,0,0]) union() {
            translate([KEY_SPACING,KEY_SPACING,-1]) cube([KEY_HOLE,KEY_HOLE,PLATE_THICKNESS+2]);
            translate([KEY_SPACING+KEY_UNIT*(1+1/2),KEY_SPACING,-1]) cube([KEY_HOLE,KEY_HOLE,PLATE_THICKNESS+2]);
            translate([KEY_SPACING+KEY_UNIT*(1+2+0.25/2),KEY_SPACING,-1]) cube([KEY_HOLE,KEY_HOLE,PLATE_THICKNESS+2]);
            translate([KEY_SPACING+KEY_UNIT*(1+2+1.25+0.25/2),KEY_SPACING,-1]) cube([KEY_HOLE,KEY_HOLE,PLATE_THICKNESS+2]);
        }
        // mods
        translate([0,4*KEY_UNIT,0]) rotate([0,0,-ANGLE]) translate([KEY_SPACING,KEY_SPACING,-1]) union() {
            cube([KEY_HOLE,KEY_HOLE,PLATE_THICKNESS+2]);
            translate([KEY_UNIT,0,0]) cube([KEY_HOLE,KEY_HOLE,PLATE_THICKNESS+2]);
        }
        translate([0,3*KEY_UNIT,0]) rotate([0,0,-ANGLE]) translate([KEY_SPACING,KEY_SPACING,-1]) union() {
            cube([KEY_HOLE,KEY_HOLE,PLATE_THICKNESS+2]);
            translate([(1+0.5/2)*KEY_UNIT,0,0]) cube([KEY_HOLE,KEY_HOLE,PLATE_THICKNESS+2]);
        }
        translate([0,2*KEY_UNIT,0]) rotate([0,0,-ANGLE]) translate([KEY_SPACING,KEY_SPACING,-1]) union() {
            cube([KEY_HOLE,KEY_HOLE,PLATE_THICKNESS+2]);
            translate([(1+0.75/2)*KEY_UNIT,0,0]) cube([KEY_HOLE,KEY_HOLE,PLATE_THICKNESS+2]);
        }
        translate([0,1*KEY_UNIT,0]) rotate([0,0,-ANGLE]) translate([KEY_SPACING,KEY_SPACING,-1]) union() {
            cube([KEY_HOLE,KEY_HOLE,PLATE_THICKNESS+2]);
            translate([(1+0.25/2)*KEY_UNIT,0,0]) cube([KEY_HOLE,KEY_HOLE,PLATE_THICKNESS+2]);
            translate([(1+1.25)*KEY_UNIT,0,0]) cube([KEY_HOLE,KEY_HOLE,PLATE_THICKNESS+2]);
        }
        translate([0,0*KEY_UNIT,0]) rotate([0,0,-ANGLE]) translate([KEY_SPACING,KEY_SPACING,-1]) union() {
            translate([(0.25/2)*KEY_UNIT,0,0]) cube([KEY_HOLE,KEY_HOLE,PLATE_THICKNESS+2]);
            translate([(1.25+0.5/2)*KEY_UNIT,0,0]) cube([KEY_HOLE,KEY_HOLE,PLATE_THICKNESS+2]);
        }
    }
}

module plate_left() {
    translate([-5.5*KEY_UNIT*cos(ANGLE)-HALF_SPACING/2,0,0])
    rotate([0,0,-ANGLE])
    difference() {
        //// plate
        union() {
            cube([4*KEY_UNIT,5*KEY_UNIT,PLATE_THICKNESS]);
            cube([5.5*KEY_UNIT,KEY_UNIT,PLATE_THICKNESS]);
            translate([0,4*KEY_UNIT,0]) hull() {
                cube([1,KEY_UNIT,PLATE_THICKNESS]);
                rotate([0,0,ANGLE]) translate([-KEY_UNIT*2,0,0]) cube([KEY_UNIT*2,KEY_UNIT,PLATE_THICKNESS]);
            }
            translate([0,3*KEY_UNIT,0]) hull() {
                cube([1,KEY_UNIT,PLATE_THICKNESS]);
                rotate([0,0,ANGLE]) translate([-KEY_UNIT*2.5,0,0]) cube([KEY_UNIT*2.5,KEY_UNIT,PLATE_THICKNESS]);
            }
            translate([0,2*KEY_UNIT,0]) hull() {
                cube([1,KEY_UNIT,PLATE_THICKNESS]);
                rotate([0,0,ANGLE]) translate([-KEY_UNIT*2.75,0,0]) cube([KEY_UNIT*2.75,KEY_UNIT,PLATE_THICKNESS]);
            }
            translate([0,1*KEY_UNIT,0]) hull() {
                cube([1,KEY_UNIT,PLATE_THICKNESS]);
                rotate([0,0,ANGLE]) translate([-KEY_UNIT*2.75,0,0]) cube([KEY_UNIT*2.75,KEY_UNIT,PLATE_THICKNESS]);
            }
            translate([0,0*KEY_UNIT,0]) hull() {
                cube([1,KEY_UNIT,PLATE_THICKNESS]);
                rotate([0,0,ANGLE]) translate([-KEY_UNIT*2.5,0,0]) cube([KEY_UNIT*2.25,KEY_UNIT,PLATE_THICKNESS]);
            }
        }
        //// holes
        for(i=[0:3]) {
            for(j=[0:3]) {
                translate([0,KEY_UNIT,0])
                translate([KEY_SPACING,KEY_SPACING,-1])
                translate([i*KEY_UNIT,j*KEY_UNIT,0]) cube([KEY_HOLE,KEY_HOLE,PLATE_THICKNESS+2]);
            }
        }
        // bottom row
        translate([KEY_SPACING,KEY_SPACING,-1]) cube([KEY_HOLE,KEY_HOLE,PLATE_THICKNESS+2]);
        translate([KEY_SPACING+KEY_UNIT*(1+0.25/2),KEY_SPACING,-1]) cube([KEY_HOLE,KEY_HOLE,PLATE_THICKNESS+2]);
        translate([KEY_SPACING+KEY_UNIT*(1.25+1+1.25/2),KEY_SPACING,-1]) cube([KEY_HOLE,KEY_HOLE,PLATE_THICKNESS+2]);
        translate([KEY_SPACING+KEY_UNIT*(1.25+2.25+1),KEY_SPACING,-1]) cube([KEY_HOLE,KEY_HOLE,PLATE_THICKNESS+2]);
        // mods
        translate([0,4*KEY_UNIT,0]) rotate([0,0,ANGLE]) translate([-KEY_UNIT*2+KEY_SPACING,KEY_SPACING,-1]) union() {
            cube([KEY_HOLE,KEY_HOLE,PLATE_THICKNESS+2]);
            translate([KEY_UNIT,0,0]) cube([KEY_HOLE,KEY_HOLE,PLATE_THICKNESS+2]);
        }
        translate([0,3*KEY_UNIT,0]) rotate([0,0,ANGLE]) translate([-KEY_UNIT*2.5+KEY_SPACING,KEY_SPACING,-1]) union() {
            translate([(0.5/2)*KEY_UNIT,0,0]) cube([KEY_HOLE,KEY_HOLE,PLATE_THICKNESS+2]);
            translate([1.5*KEY_UNIT,0,0]) cube([KEY_HOLE,KEY_HOLE,PLATE_THICKNESS+2]);
        }
        translate([0,2*KEY_UNIT,0]) rotate([0,0,ANGLE]) translate([-KEY_UNIT*2.75+KEY_SPACING,KEY_SPACING,-1]) union() {
            translate([(0.75/2)*KEY_UNIT,0,0]) cube([KEY_HOLE,KEY_HOLE,PLATE_THICKNESS+2]);
            translate([1.75*KEY_UNIT,0,0]) cube([KEY_HOLE,KEY_HOLE,PLATE_THICKNESS+2]);
        }
        translate([0,1*KEY_UNIT,0]) rotate([0,0,ANGLE]) translate([-KEY_UNIT*2.75+KEY_SPACING,KEY_SPACING,-1]) union() {
            translate([(0.75/2)*KEY_UNIT,0,0]) cube([KEY_HOLE,KEY_HOLE,PLATE_THICKNESS+2]);
            translate([1.75*KEY_UNIT,0,0]) cube([KEY_HOLE,KEY_HOLE,PLATE_THICKNESS+2]);
        }
        translate([0,0*KEY_UNIT,0]) rotate([0,0,ANGLE]) translate([-KEY_UNIT*2.5+KEY_SPACING,KEY_SPACING,-1]) union() {
            translate([(0.25/2)*KEY_UNIT,0,0]) cube([KEY_HOLE,KEY_HOLE,PLATE_THICKNESS+2]);
            translate([(1.25+0.25/2)*KEY_UNIT,0,0]) cube([KEY_HOLE,KEY_HOLE,PLATE_THICKNESS+2]);
        }

    }
}

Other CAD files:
case/core/cute/barnacle-case_core_cute.3mf
case/core/wood/barnacle-wood_core.FCStd
case/core/cute/barnacle-cute_core.FCStd
case/core/versatile/barnacle-case-center_knob.3mf
case/barnacle-bottom_plate.dxf
case/barnacle-plate_fixer_bottom.3mf
case/barnacle-plate_fixer_top.3mf
case/barnacle-plate_left.3mf
case/barnacle-plate_right.3mf
case/barnacle-plate_tpu_left.3mf
case/barnacle-shell.3mf
case/core/versatile/barnacle-case-core_cross.3mf
case/core/versatile/barnacle-case_core_2.25keys2knobs.3mf
case/core/versatile/barnacle-case_core_2x3.3mf
case/core/versatile/barnacle-case_core_3x3.3mf
case/core/versatile/barnacle-case_core_oled.3mf
case/core/versatile/barnacle-versatile_core.FCStd
prototyping/plate_left_15.stl
prototyping/plate_middle.stl
prototyping/plate_right_15.stl

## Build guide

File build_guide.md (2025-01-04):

# build guide

## bom

### shell pcb

- [ ] shell pcb
- [ ] 61 kailh mx hot swap sockets
- [ ] 61 smd diodes (1N4148W)
- [ ] 2x single row 11 pin 2.54mm female pin header (the cheap ones you can get from eBay / AliExpress)
- [ ] silver wire or diode legs for the pin header

> [!WARNING]
> Be aware that if you don't use the hot swappable headers to connect the pcbs the core pcb will sit slightly lower. You'll have to adjust the core case.

optional:
- [ ] underglow: 22x SMD RGB leds (SK6812MINI-E)
- [ ] per key: 61x RGB leds (SK6812MINI-E), underglow leds are required
- [ ] 2x stabilizer

> [!NOTE]  
> The pcb has holes for stabilizers but the plate does not as I use mine without stabilizers. This works great with switches with good tolerances like Gateron.

### core pcb

- [ ] core pcb
- [ ] 1x [0xCB Helios](https://keeb.supply/products/0xcb-helios) controller
- [ ] single row 2.54mm female pin header for the controller (the cheap ones you can get from eBay / AliExpress)
- [ ] silver wire or diode legs for the pin header

Depending on your core pcb you might need additional headers, hot swap sockets or hardware but that should be straight forward

> [!TIP]
> I highly recommend mill-max hot swap sockets for the switch thats directly on the controller footprint. I used 3305 but there should be enough space with the hot swappable pin header for the other socket types from mill-max.

### 3dp case

- [ ] 11x [M3 x 5.7 heat set inserts](https://cnckitchen.store/products/heat-set-insert-m3-x-5-7-100-pieces)
- [ ] 8x M3 5-8mm screws (visible from the bottom)
- [ ] 3x M3 5mm screws (on the inside)
- [ ] 3d printed parts: both shell pieces, both plates, all four plate fixers, core piece
- [ ] 3mm acrylic bottom plate
- [ ] 6x 8mm rubber feet

### additional hardware depending on layout

<details>
<summary>encoder core</summary>

- [ ] 2 kailh mx hot swap sockets
- [ ] 1 smd diode (1N4148W) per key and encoder
- [ ] encoder (2 at most)
    - ec11 rotary encoder with a short (d) shaft (15mm)
    - knob
</details>

<details>
<summary>versatile core</summary>

- [ ] 1 smd diode (1N4148W) per key and encoder
- [ ] encoder (2 at most)
    - ec11 rotary encoder with a short (d) shaft (15mm)
    - knob
- [ ] oled screen
    - 1.3" oled screen
    - pair of single row 4 pin 2.54mm pin headers (the cheap ones you can get from eBay / AliExpress)
    - 4x M2 heat set inserts
    - 4x M2 5mm screws
</details>

<details>
<summary>cute core</summary>

- [ ] 4 kailh mx hot swap socket
- [ ] 4 smd diode (1N4148W)
</details>

<details>
<summary>special core</summary>

still WIP
</details>

## assembly

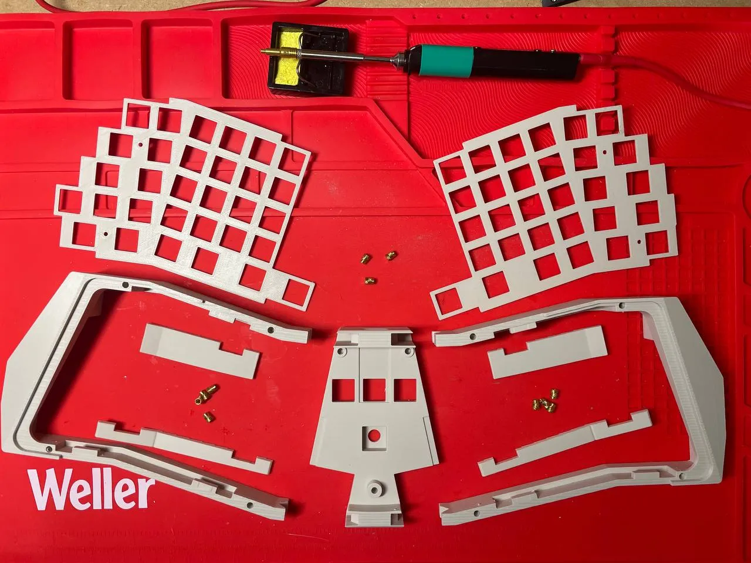
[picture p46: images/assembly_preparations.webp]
preparations


### preparing the case

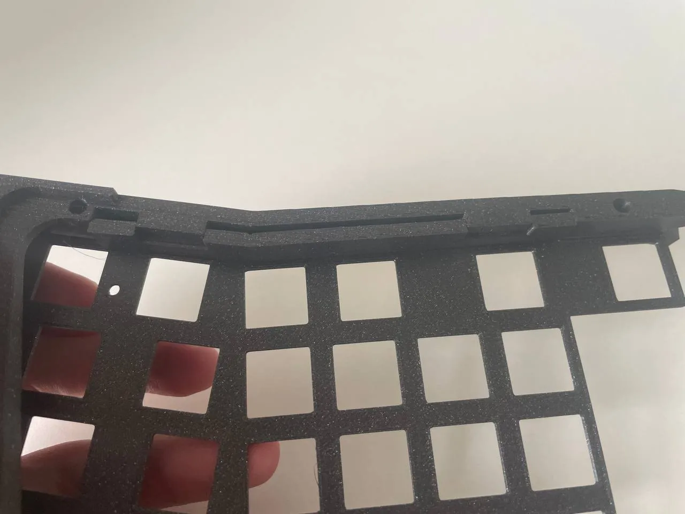
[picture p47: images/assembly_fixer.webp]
fixer
1. Insert the left plate in the left shell and fixate it with the fixer pieces. Do the same with the other half. If the fixer pieces don't snug into place nicely you can force them into place with a chopstick and hammer. 
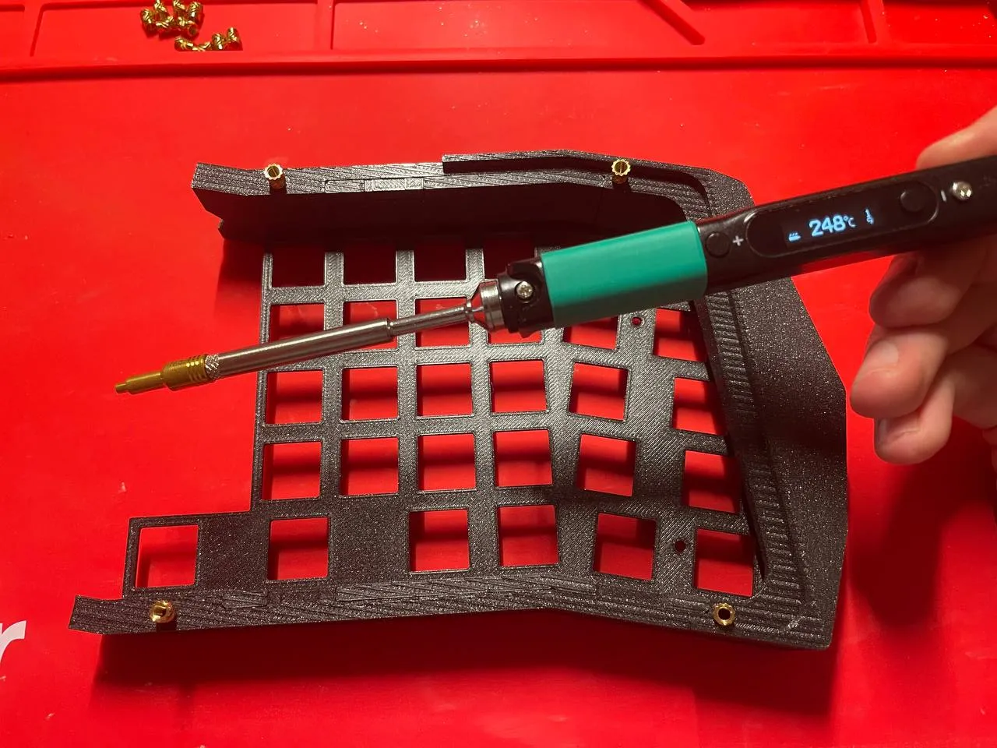
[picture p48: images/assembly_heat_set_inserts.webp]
heat set inserts
2. Heat up your soldering iron, insert the heat set inserts and gently push them inside the shell pieces as well as the core piece. Make sure to insert them exactly perpendicular so they sit flush with the surface. 

### preparing the shell pcb

1. Start soldering the hot swap sockets, smd diodes and optionally the RGB leds.
2. After that solder the single row headers. Make sure that they go on the opposite side (see markings) and that they are soldered on straight.

### preparing the core pcb

1. If your core supports it and you want to use a switch under the controller please solder the two mill-max sockets under the controller first. Also remember later to cut the pin header directly beneath the switch flush.
2. Start soldering the single row headers for the controller. Make sure that they are soldered on straight.
3. Align the Helios, insert the silver wire, cut it roughly flush and fixate it with solder. Make sure that you don't heat it up too long so you don't get any solder inside in the pin header. 
4. If you are using RGB leds connect the jumper with the marked or non-marked pad:
    - left jumper pad for the input pin: left (marked) for the Helios' pin 25, right for other controllers (D1)
    - right jumper pad for the power source: left (marked) for raw/5V, right for 3.3V
5. Solder the remaining components specific to the chosen core: kailh hot swap sockets, diodes, encoders or pin headers for an oled screen.
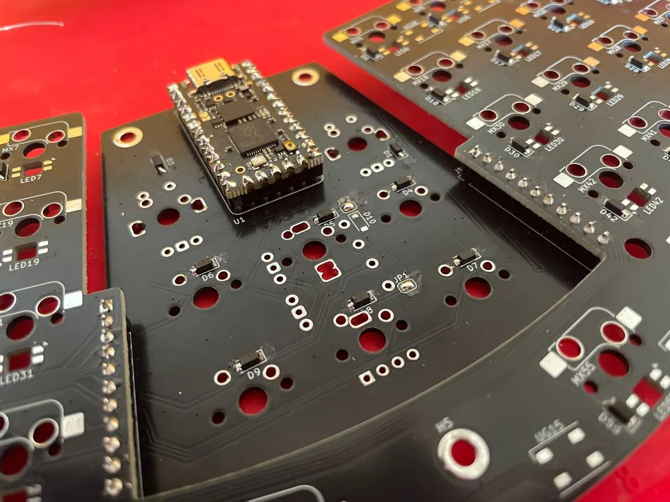
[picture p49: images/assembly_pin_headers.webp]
pin headers
6. Lastly align the core pcb with the shell pcb, insert the silver wire, cut it roughly flush and fixate it with solder. Make sure that you don't heat it up too long so you don't get any solder inside in the pin header. 

### test the pcb

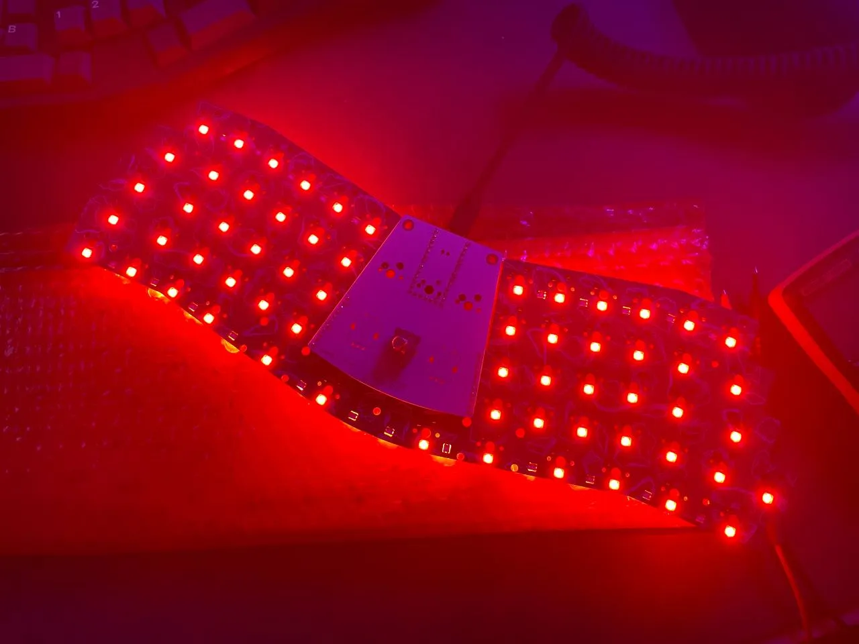
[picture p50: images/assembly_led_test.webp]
led test
This is important as some components like the outer columns, pin headers and leds on the edge are difficult to reflow later if they are not soldered on properly. 

1. Compile the firmware `make barnacle:default` (<https://github.com/floookay/qmk_firmware/keyboards/barnacle>)
2. Plug in the keyboard, click the reset button on the Helios controller and upload the compiled firmware.
3. Check that all keys and leds work.

### install the pcb

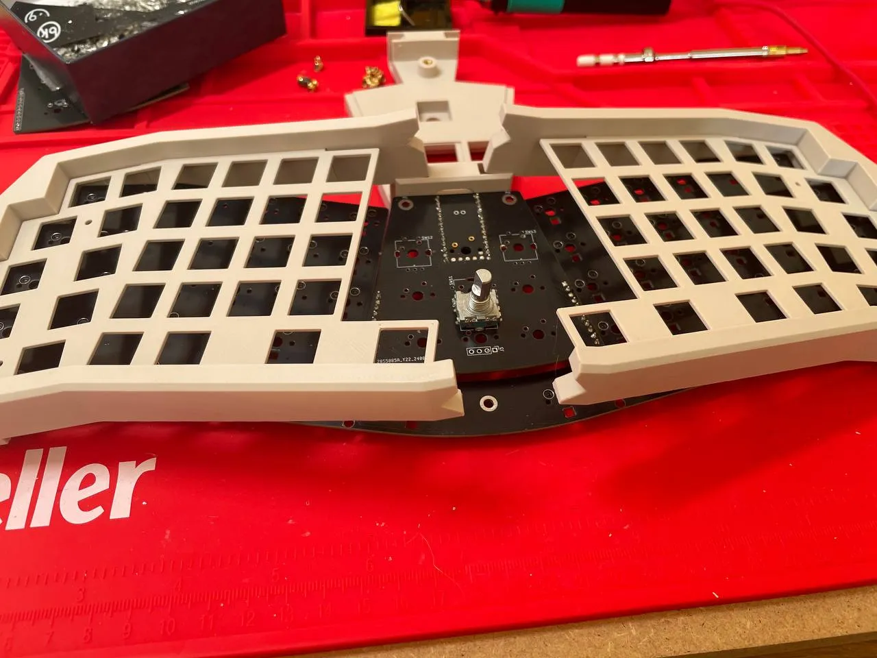
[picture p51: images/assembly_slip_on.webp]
assembly slip on
1. Slip on the shell case on the pcb like this: 
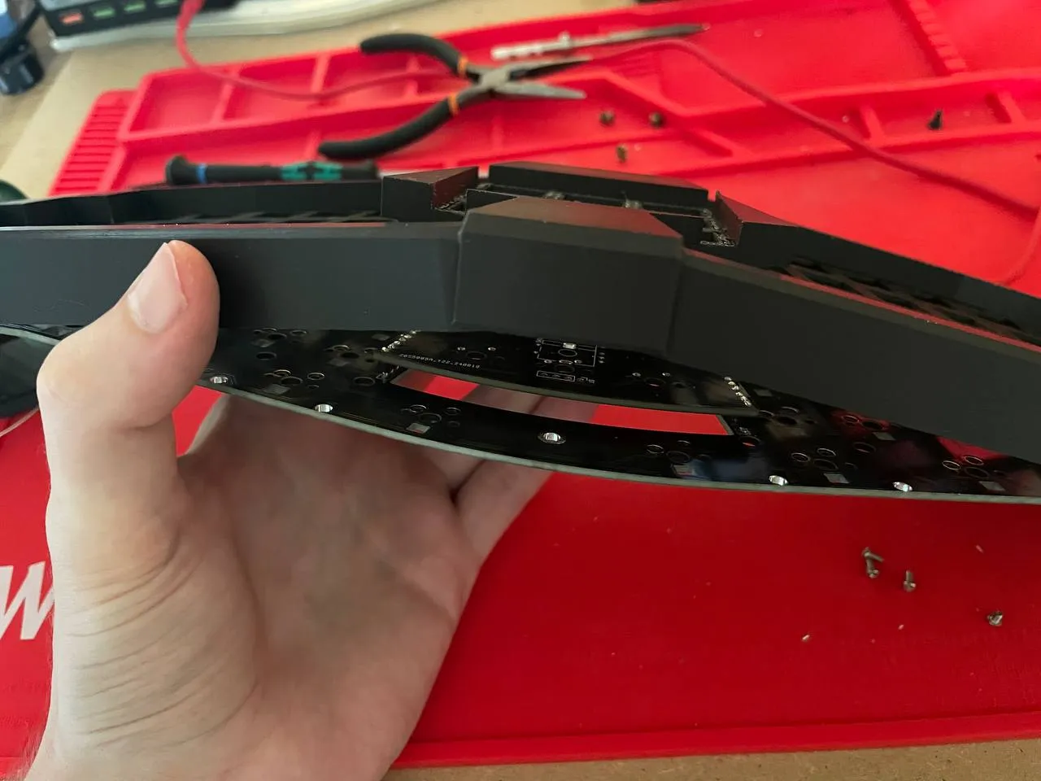
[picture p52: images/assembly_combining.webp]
assembly combining
2. Add the core case piece and press it downwards: 
3. Screw in the three screws in the middle. 2 on the core pcb, 1 on the shell below.
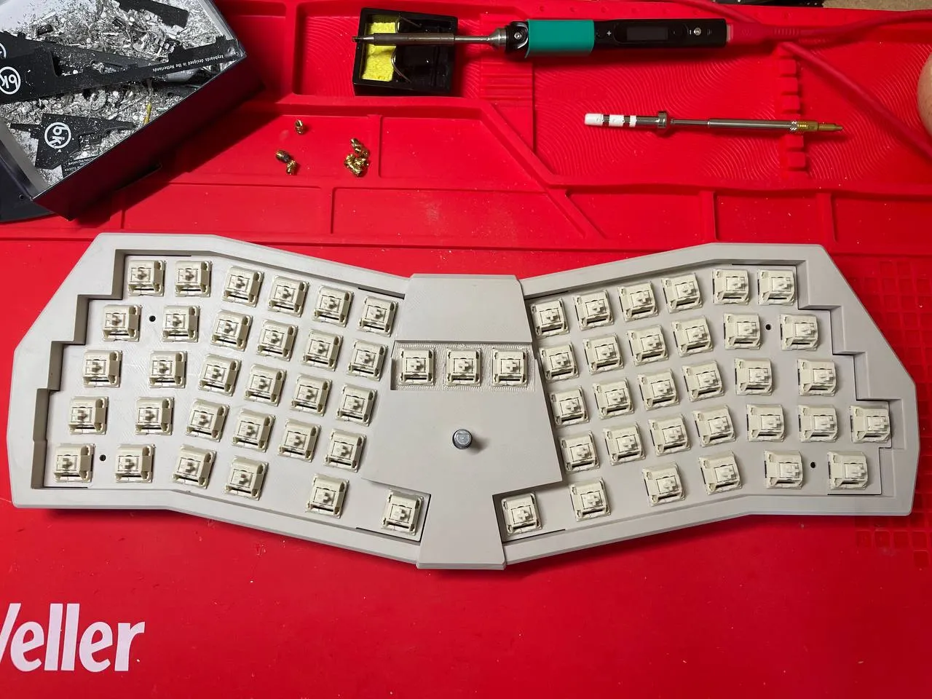
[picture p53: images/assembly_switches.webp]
assembly switches
4. Put in the MX switches. Make sure that the switch legs aren't bent and that they are snapped into the plate. 
5. Screw in the acrylic bottom with the remaining 8 screws.
6. Add the rubber feet to the acrylic plate.

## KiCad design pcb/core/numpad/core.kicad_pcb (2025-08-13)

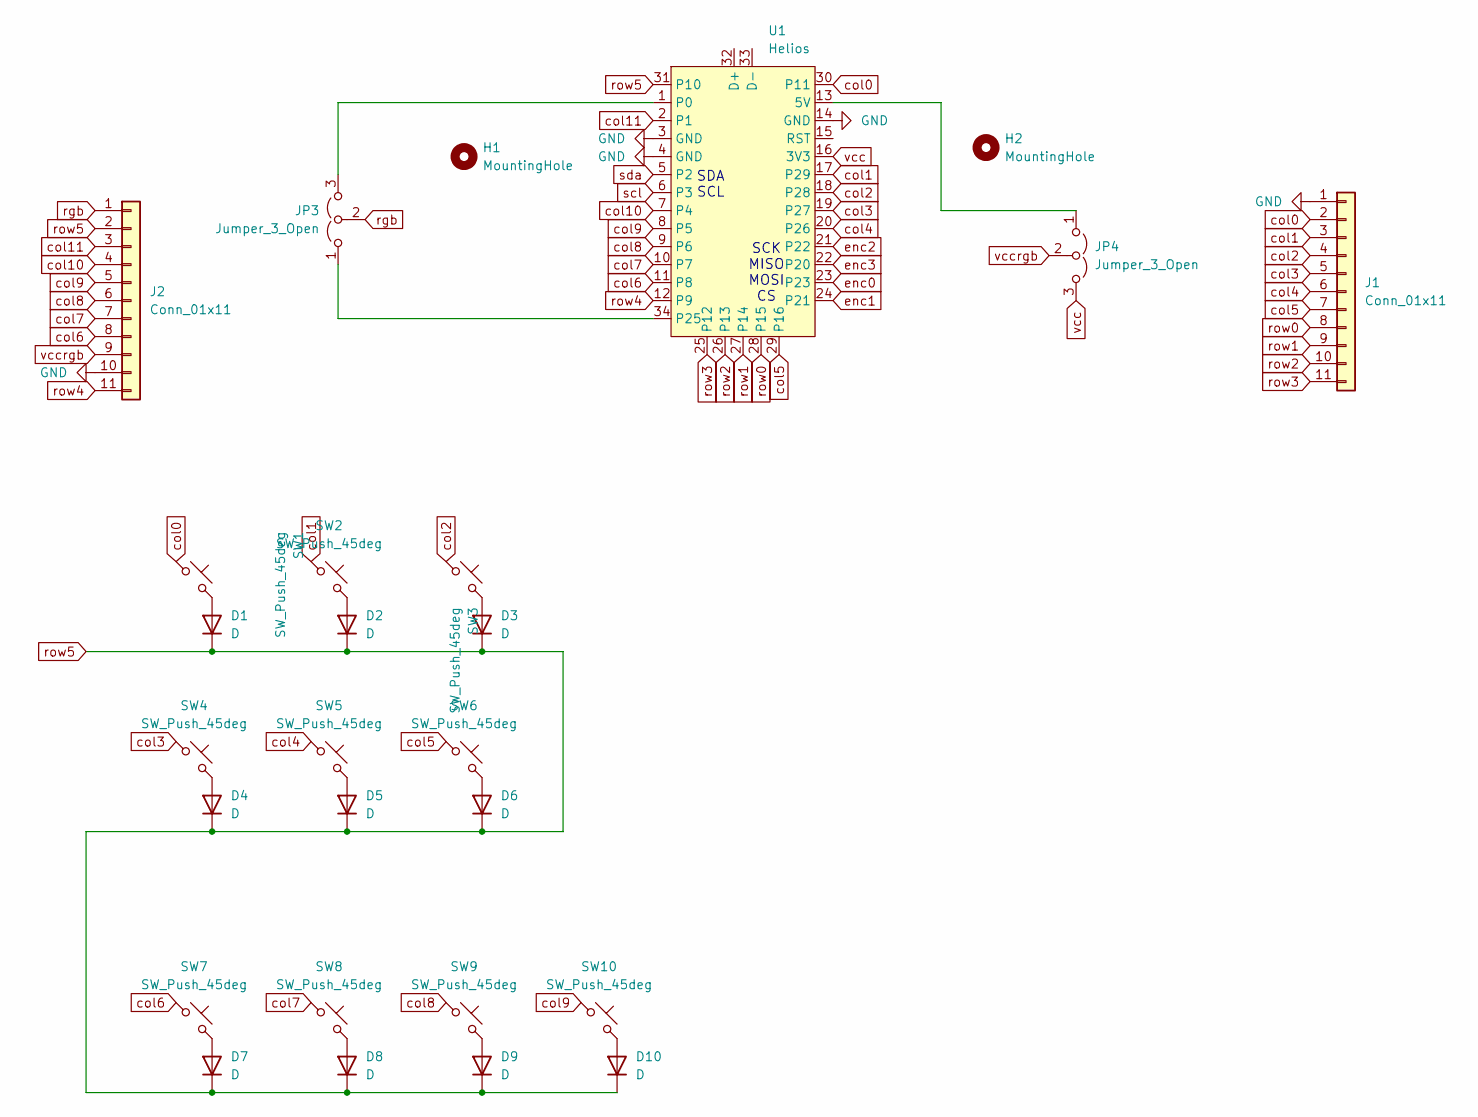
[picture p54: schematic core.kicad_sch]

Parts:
D1, D2, D3, D4, D5, D6, D7, D8, D9, D10: D; D_SOD-123-minimal
H1, H2: MountingHole; MountingHole_3.2mm_M3_DIN965_Pad
J1, J2: Conn_01x11; PinHeader_1x11_P2.54mm_Vertical
JP3, JP4: Jumper_3_Open; SolderJumper-3_P1.3mm_Open_RoundedPad1.0x1.5mm
SW1, SW3, SW4, SW5, SW6, SW7, SW8, SW9, SW10: SW_Push_45deg; SW_MX_HS_S_CPG151101S11_1u
SW2: SW_Push_45deg; SW_MX_1u
U1: Helios; Helios_AH_USBup

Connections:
GND: J1.1, J2.10, U1.3 (GND), U1.4 (GND), U1.14 (GND)
unnamed: D1.2 (A), SW1.2
unnamed: D2.2 (A), SW2.2
unnamed: D3.2 (A), SW3.2
unnamed: D4.2 (A), SW4.2
unnamed: D5.2 (A), SW5.2
unnamed: D6.2 (A), SW6.2
unnamed: D7.2 (A), SW7.2
unnamed: D8.2 (A), SW8.2
unnamed: D9.2 (A), SW9.2
unnamed: D10.2 (A), SW10.2
unnamed: JP3.1 (A), U1.34 (P25)
unnamed: JP3.3 (B), U1.1 (P0)
unnamed: JP4.1 (A), U1.13 (5V)
col0: J1.2, SW1.1, U1.30 (P11)
col1: J1.3, SW2.1, U1.17 (P29)
col2: J1.4, SW3.1, U1.18 (P28)
col3: J1.5, SW4.1, U1.19 (P27)
col4: J1.6, SW5.1, U1.20 (P26)
col5: J1.7, SW6.1, U1.29 (P16)
col6: J2.8, SW7.1, U1.11 (P8)
col7: J2.7, SW8.1, U1.10 (P7)
col8: J2.6, SW9.1, U1.9 (P6)
col9: J2.5, SW10.1, U1.8 (P5)
col10: J2.4, U1.7 (P4)
col11: J2.3, U1.2 (P1)
enc0: U1.23
enc1: U1.24 (P21)
enc2: U1.21 (P22)
enc3: U1.22 (P20)
rgb: J2.1, JP3.2 (C)
row0: J1.8, U1.28 (P15)
row1: J1.9, U1.27 (P14)
row2: J1.10, U1.26 (P13)
row3: J1.11, U1.25 (P12)
row4: J2.11, U1.12 (P9)
row5: D1.1 (K), D2.1 (K), D3.1 (K), D4.1 (K), D5.1 (K), D6.1 (K), D7.1 (K), D8.1 (K), D9.1 (K), D10.1 (K), J2.2, U1.31 (P10)
scl: U1.6 (P3)
sda: U1.5 (P2)
vcc: JP4.3 (B), U1.16 (3V3)
vccrgb: J2.9, JP4.2 (C)

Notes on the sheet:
SDA SCL
SCK MISO MOSI CS

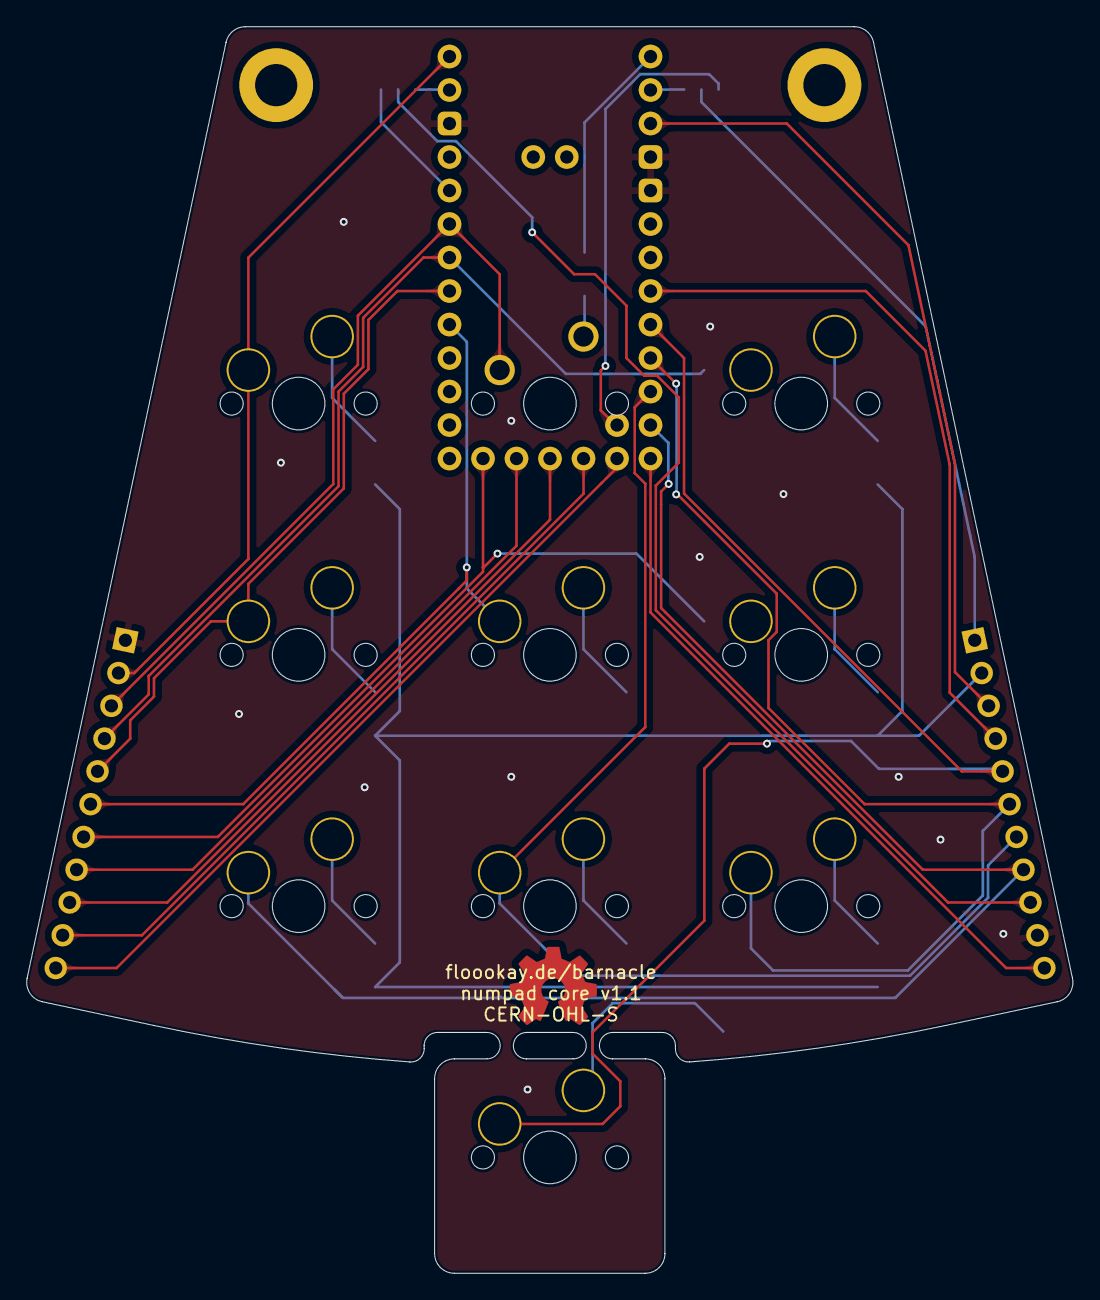
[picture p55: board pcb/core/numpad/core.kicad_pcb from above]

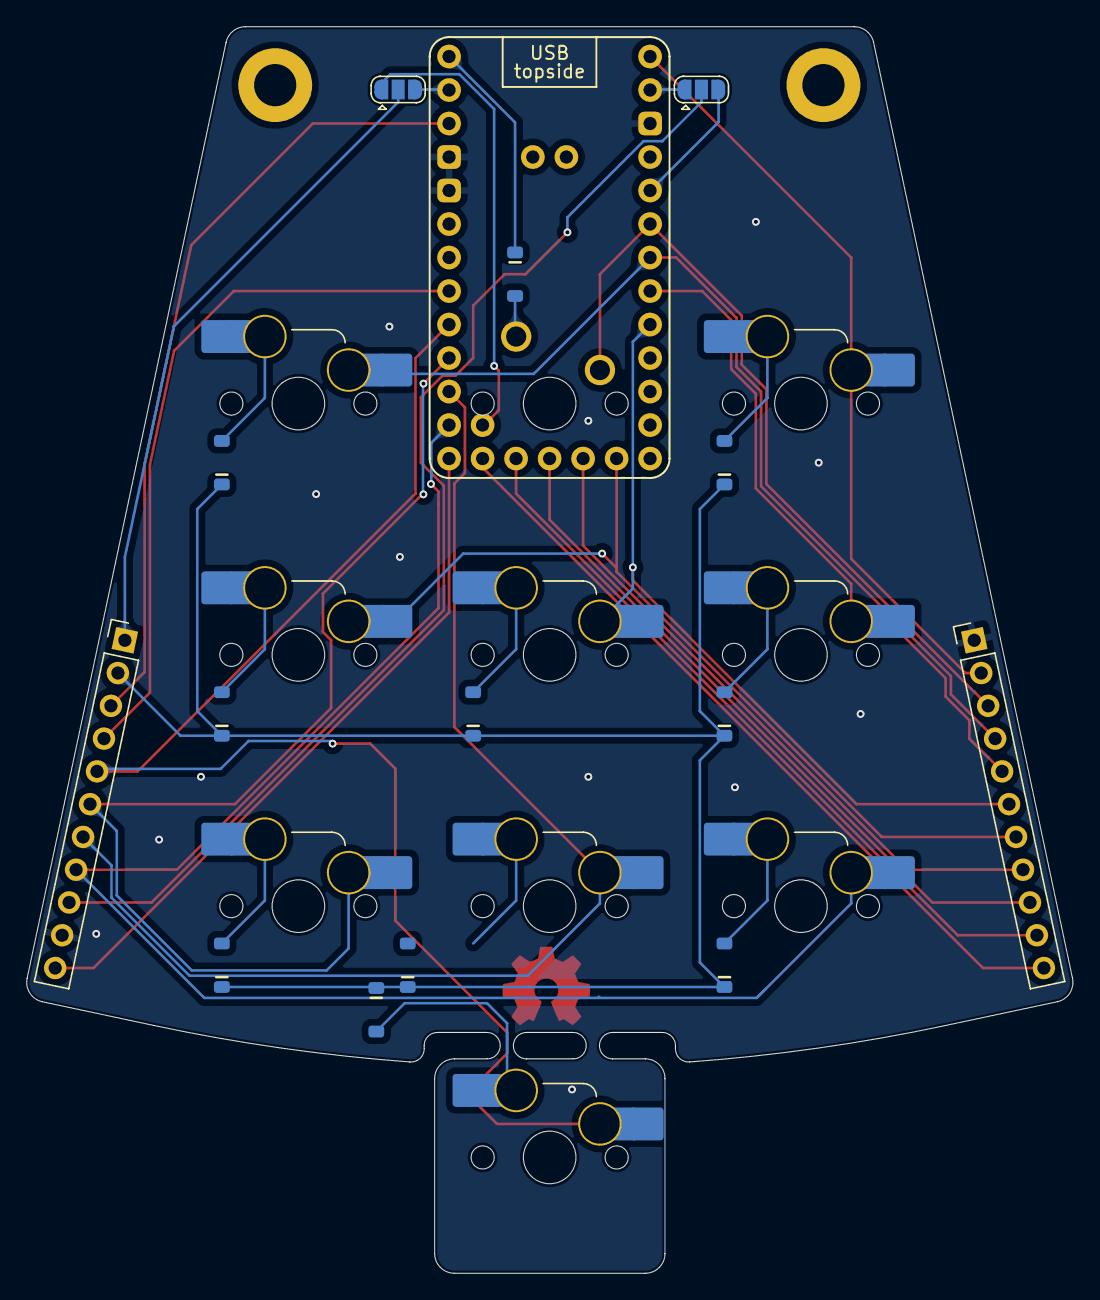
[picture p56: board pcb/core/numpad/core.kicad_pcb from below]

Board: 2 copper layers, 79.3 x 94.5 mm, 27 parts (24 on the bottom side), 35 nets.

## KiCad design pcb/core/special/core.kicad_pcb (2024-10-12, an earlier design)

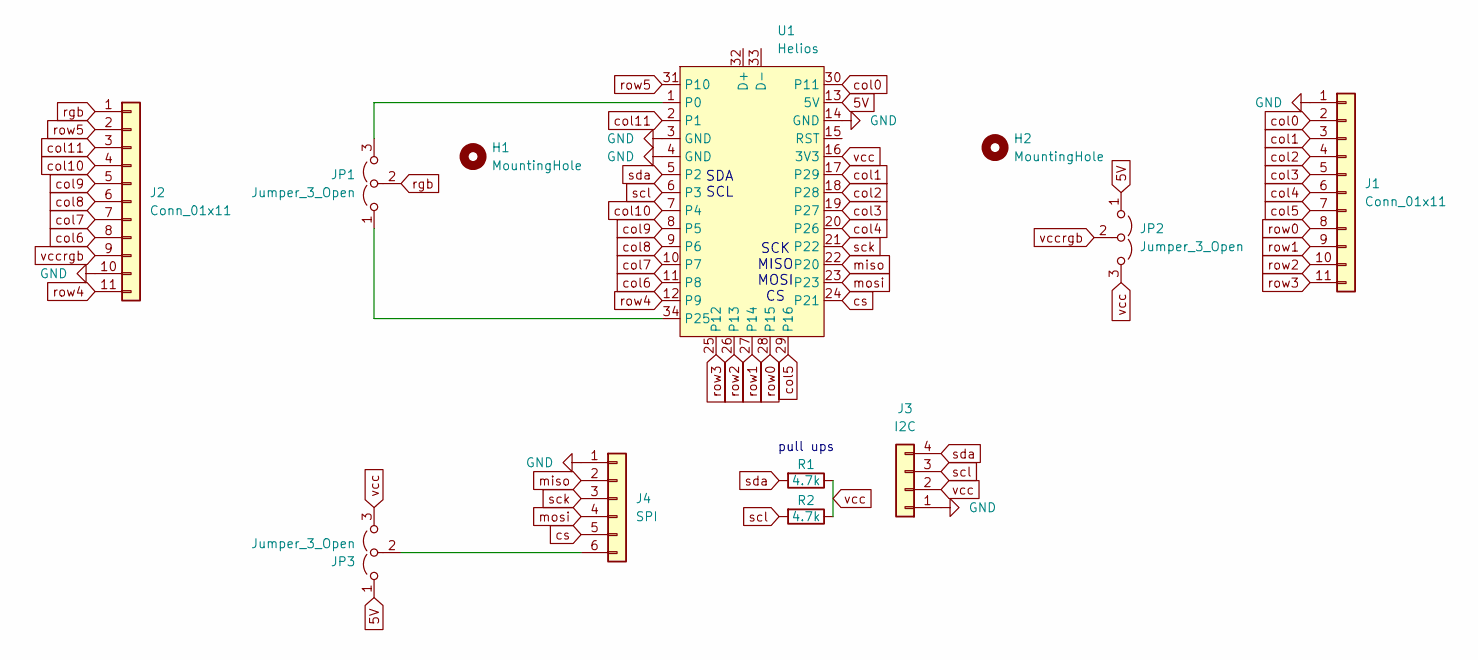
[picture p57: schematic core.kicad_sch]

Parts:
H1, H2: MountingHole; MountingHole_3.2mm_M3_DIN965_Pad
J1, J2: Conn_01x11; PinHeader_1x11_P2.54mm_Vertical
J3: I2C; PinHeader_1x04_P2.54mm_Vertical
J4: SPI; PinHeader_1x06_P2.54mm_Vertical
JP1, JP2, JP3: Jumper_3_Open; SolderJumper-3_P1.3mm_Open_RoundedPad1.0x1.5mm
R1, R2: 4.7k; R_Axial_DIN0207_L6.3mm_D2.5mm_P7.62mm_Horizontal; LCSC C269746
U1: Helios; Helios_AH_USBup

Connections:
5V: JP2.1 (A), JP3.1 (A), U1.13 (5V)
GND: J1.1, J2.10, J3.1, J4.1, U1.3 (GND), U1.4 (GND), U1.14 (GND)
unnamed: J4.6, JP3.2 (C)
unnamed: JP1.1 (A), U1.34 (P25)
unnamed: JP1.3 (B), U1.1 (P0)
col0: J1.2, U1.30 (P11)
col1: J1.3, U1.17 (P29)
col2: J1.4, U1.18 (P28)
col3: J1.5, U1.19 (P27)
col4: J1.6, U1.20 (P26)
col5: J1.7, U1.29 (P16)
col6: J2.8, U1.11 (P8)
col7: J2.7, U1.10 (P7)
col8: J2.6, U1.9 (P6)
col9: J2.5, U1.8 (P5)
col10: J2.4, U1.7 (P4)
col11: J2.3, U1.2 (P1)
cs: J4.5, U1.24 (P21)
miso: J4.2, U1.22 (P20)
mosi: J4.4, U1.23
rgb: J2.1, JP1.2 (C)
row0: J1.8, U1.28 (P15)
row1: J1.9, U1.27 (P14)
row2: J1.10, U1.26 (P13)
row3: J1.11, U1.25 (P12)
row4: J2.11, U1.12 (P9)
row5: J2.2, U1.31 (P10)
sck: J4.3, U1.21 (P22)
scl: J3.3, R2.2, U1.6 (P3)
sda: J3.4, R1.2, U1.5 (P2)
vcc: J3.2, JP2.3 (B), JP3.3 (B), R1.1, R2.1, U1.16 (3V3)
vccrgb: J2.9, JP2.2 (C)

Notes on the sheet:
pull ups
SDA SCL
SCK MISO MOSI CS

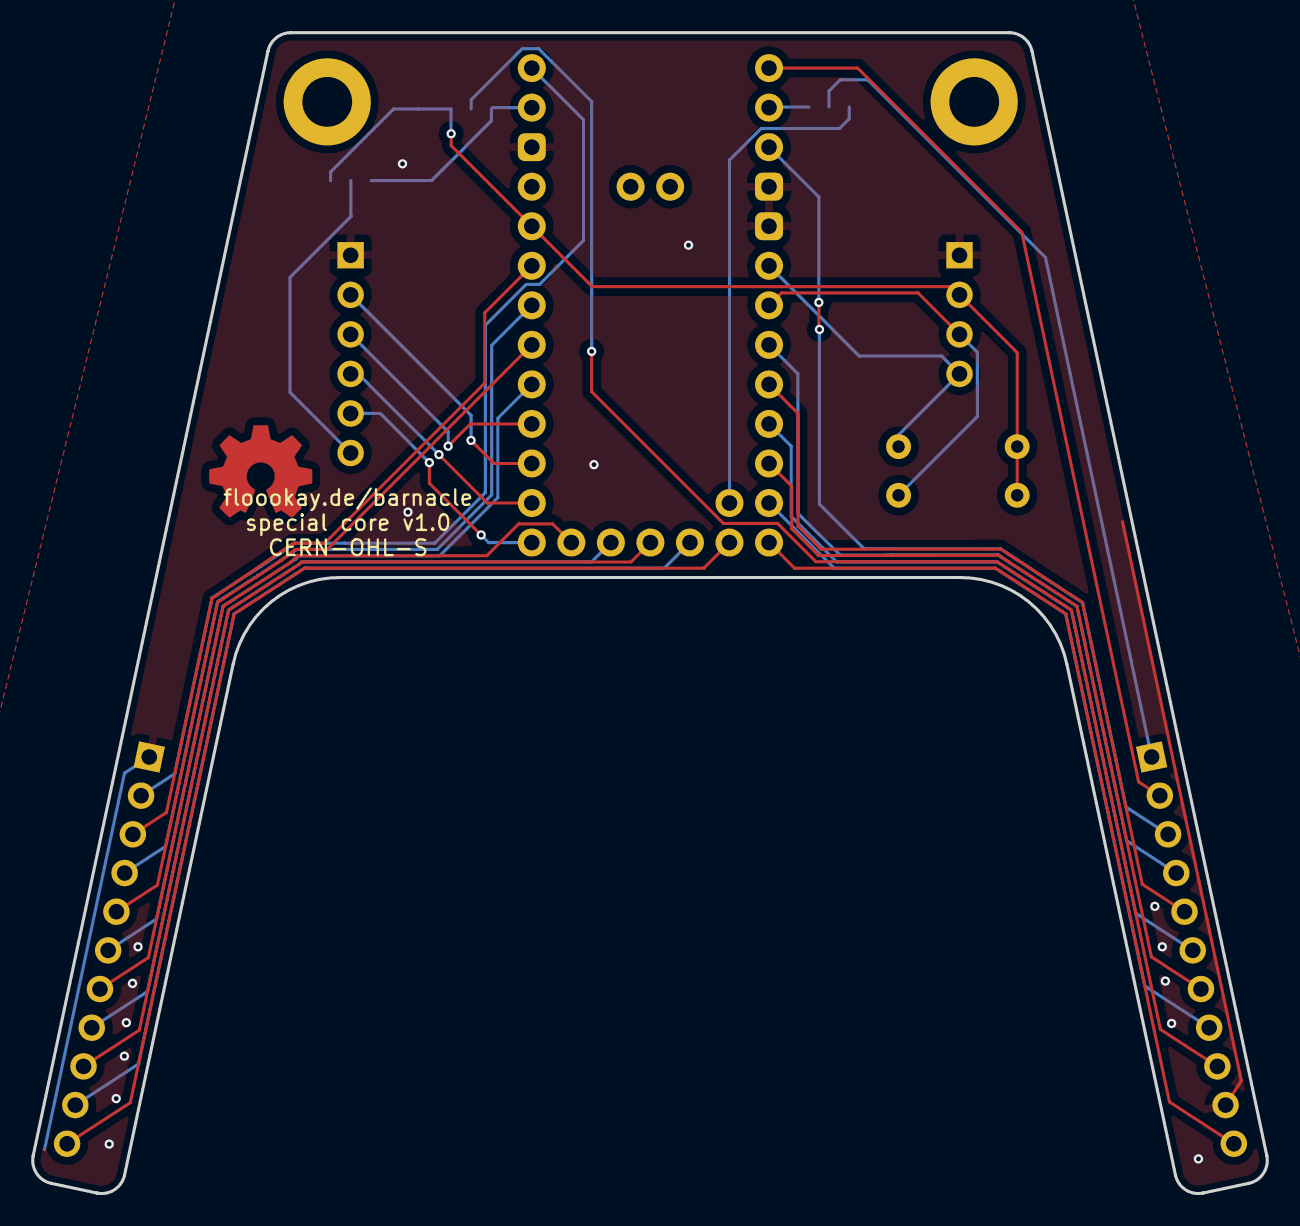
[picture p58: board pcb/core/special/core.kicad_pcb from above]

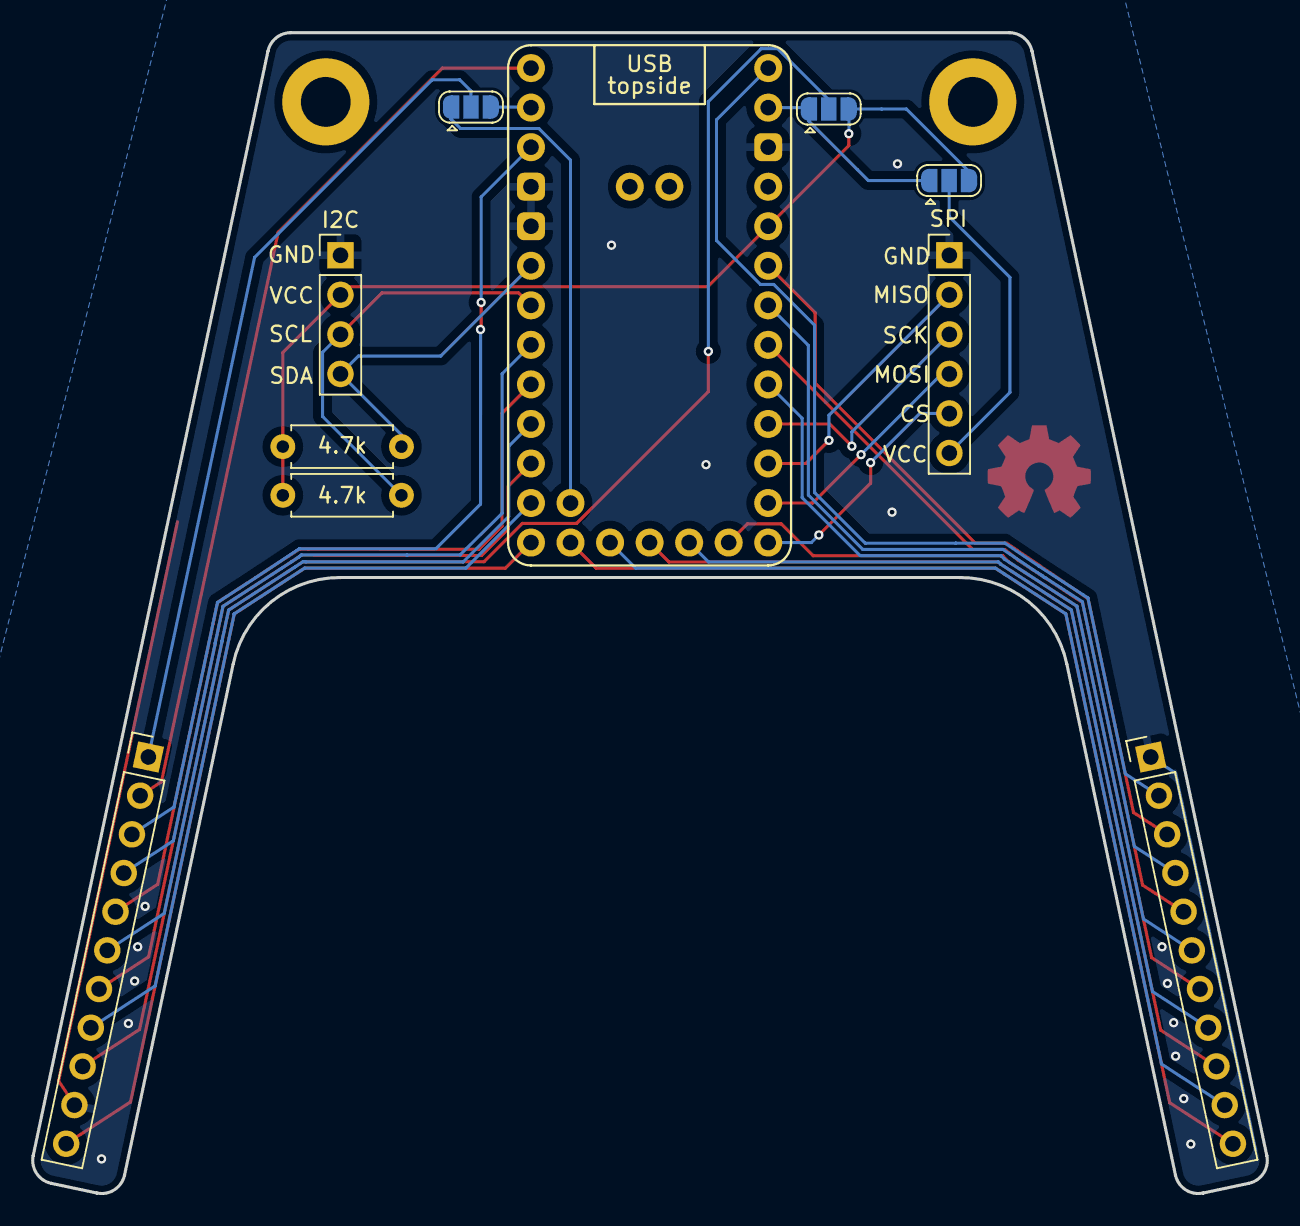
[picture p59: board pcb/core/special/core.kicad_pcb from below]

Board: 2 copper layers, 79.3 x 74.6 mm, 12 parts (10 on the bottom side), 32 nets.

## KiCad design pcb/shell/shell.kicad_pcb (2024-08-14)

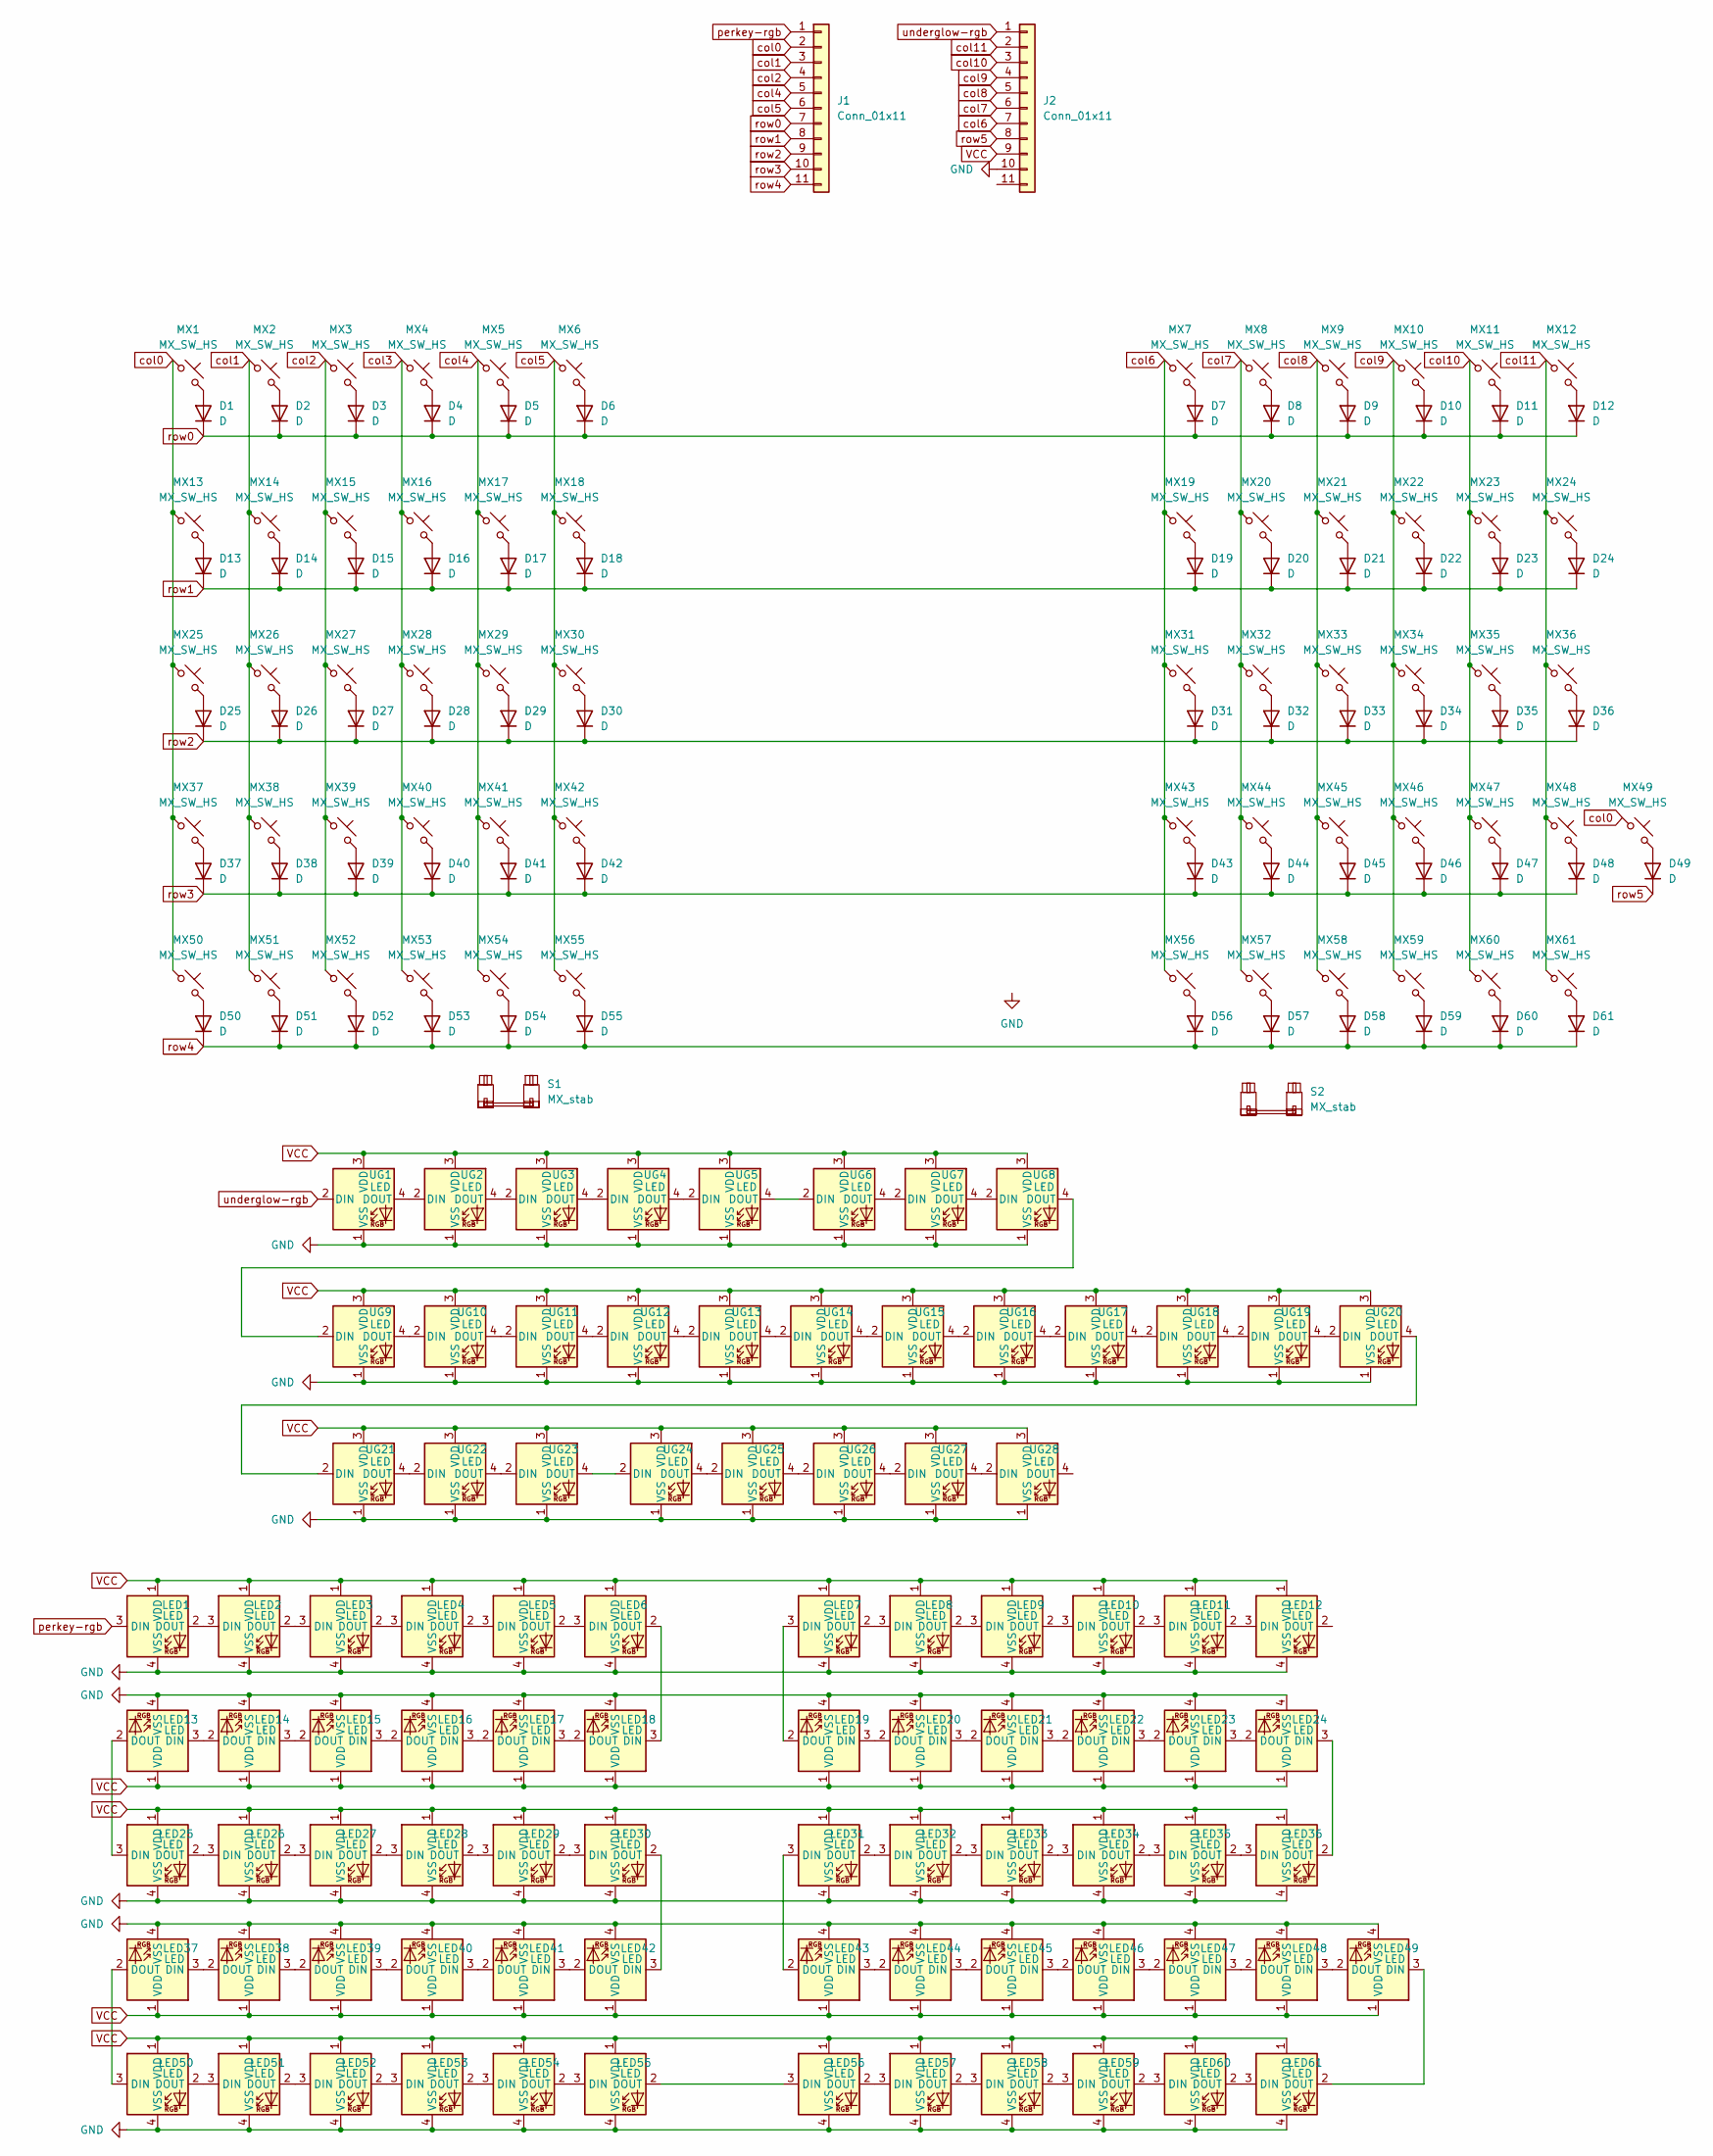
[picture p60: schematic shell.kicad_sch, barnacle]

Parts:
D1, D2, D3, D4, D5, D6, D7, D8, D9, D10, D11, D12, D13, D14, D15, D16, D17, D18, D19, D20, D21, D22, D23, D24, D25, D26, D27, D28, D29, D30, D31, D32, D33, D34, D35, D36, D37, D38, D39, D40, D41, D42, D43, D44, D45, D46, D47, D48, D49, D50, D51, D52, D53, D54, D55, D56, D57, D58, D59, D60, D61: D; D_SOD-123
J1, J2: Conn_01x11; PinSocket_1x11_P2.54mm_Vertical
LED1, LED2, LED3, LED4, LED5, LED6, LED7, LED8, LED9, LED10, LED11, LED12, LED25, LED26, LED27, LED28, LED29, LED30, LED31, LED32, LED33, LED34, LED35, LED36, LED50, LED51, LED52, LED53, LED54, LED55, LED56, LED57, LED58, LED59, LED60, LED61: LED; LED_MX_6028R-ROT
LED13, LED14, LED15, LED16, LED17, LED18, LED19, LED20, LED21, LED22, LED23, LED24, LED37, LED38, LED39, LED40, LED41, LED42, LED43, LED44, LED45, LED46, LED47, LED48, LED49: LED; LED_MX_6028R
MX1, MX2, MX3, MX4, MX5, MX6, MX7, MX8, MX9, MX10, MX11, MX12, MX14, MX15, MX16, MX17, MX18, MX19, MX20, MX21, MX22, MX23, MX26, MX27, MX28, MX29, MX30, MX31, MX32, MX33, MX34, MX35, MX38, MX39, MX40, MX41, MX42, MX43, MX44, MX45, MX46, MX47, MX49, MX52, MX54, MX55, MX56, MX57: MX_SW_HS; SW_MX_HS_CPG151101S11_1u
MX13, MX24, MX61: MX_SW_HS; SW_MX_HS_CPG151101S11_1.5u
MX25, MX36, MX37: MX_SW_HS; SW_MX_HS_CPG151101S11_1.75u
MX48, MX50, MX51, MX53, MX58, MX59, MX60: MX_SW_HS; SW_MX_HS_CPG151101S11_1.25u
S1: MX_stab; STAB_MX_P_2.25u
S2: MX_stab; STAB_MX_P_2u
UG1, UG2, UG3, UG4, UG5, UG6, UG7, UG8, UG9, UG10, UG11, UG12, UG13, UG14, UG15, UG16, UG17, UG18, UG19, UG20, UG21, UG22, UG23, UG24, UG25, UG26, UG27, UG28: LED; LED_SK6812_PLCC4_5.0x5.0mm_P3.2mm

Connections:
GND: J2.10, LED1.4 (VSS), LED2.4 (VSS), LED3.4 (VSS), LED4.4 (VSS), LED5.4 (VSS), LED6.4 (VSS), LED7.4 (VSS), LED8.4 (VSS), LED9.4 (VSS), LED10.4 (VSS), LED11.4 (VSS), LED12.4 (VSS), LED13.4 (VSS), LED14.4 (VSS), LED15.4 (VSS), LED16.4 (VSS), LED17.4 (VSS), LED18.4 (VSS), LED19.4 (VSS), LED20.4 (VSS), LED21.4 (VSS), LED22.4 (VSS), LED23.4 (VSS), LED24.4 (VSS), LED25.4 (VSS), LED26.4 (VSS), LED27.4 (VSS), LED28.4 (VSS), LED29.4 (VSS), LED30.4 (VSS), LED31.4 (VSS), LED32.4 (VSS), LED33.4 (VSS), LED34.4 (VSS), LED35.4 (VSS), LED36.4 (VSS), LED37.4 (VSS), LED38.4 (VSS), LED39.4 (VSS), LED40.4 (VSS), LED41.4 (VSS), LED42.4 (VSS), LED43.4 (VSS), LED44.4 (VSS), LED45.4 (VSS), LED46.4 (VSS), LED47.4 (VSS), LED48.4 (VSS), LED49.4 (VSS), LED50.4 (VSS), LED51.4 (VSS), LED52.4 (VSS), LED53.4 (VSS), LED54.4 (VSS), LED55.4 (VSS), LED56.4 (VSS), LED57.4 (VSS), LED58.4 (VSS), LED59.4 (VSS), LED60.4 (VSS), LED61.4 (VSS), UG1.1 (VSS), UG2.1 (VSS), UG3.1 (VSS), UG4.1 (VSS), UG5.1 (VSS), UG6.1 (VSS), UG7.1 (VSS), UG8.1 (VSS), UG9.1 (VSS), UG10.1 (VSS), UG11.1 (VSS), UG12.1 (VSS), UG13.1 (VSS), UG14.1 (VSS), UG15.1 (VSS), UG16.1 (VSS), UG17.1 (VSS), UG18.1 (VSS), UG19.1 (VSS), UG20.1 (VSS), UG21.1 (VSS), UG22.1 (VSS), UG23.1 (VSS), UG24.1 (VSS), UG25.1 (VSS), UG26.1 (VSS), UG27.1 (VSS), UG28.1 (VSS)
unnamed: D1.2 (A), MX1.2
unnamed: D2.2 (A), MX2.2
unnamed: D3.2 (A), MX3.2
unnamed: D4.2 (A), MX4.2
unnamed: D5.2 (A), MX5.2
unnamed: D6.2 (A), MX6.2
unnamed: D7.2 (A), MX7.2
unnamed: D8.2 (A), MX8.2
unnamed: D9.2 (A), MX9.2
unnamed: D10.2 (A), MX10.2
unnamed: D11.2 (A), MX11.2
unnamed: D12.2 (A), MX12.2
unnamed: D13.2 (A), MX13.2
unnamed: D14.2 (A), MX14.2
unnamed: D15.2 (A), MX15.2
unnamed: D16.2 (A), MX16.2
unnamed: D17.2 (A), MX17.2
unnamed: D18.2 (A), MX18.2
unnamed: D19.2 (A), MX19.2
unnamed: D20.2 (A), MX20.2
unnamed: D21.2 (A), MX21.2
unnamed: D22.2 (A), MX22.2
unnamed: D23.2 (A), MX23.2
unnamed: D24.2 (A), MX24.2
unnamed: D25.2 (A), MX25.2
unnamed: D26.2 (A), MX26.2
unnamed: D27.2 (A), MX27.2
unnamed: D28.2 (A), MX28.2
unnamed: D29.2 (A), MX29.2
unnamed: D30.2 (A), MX30.2
unnamed: D31.2 (A), MX31.2
unnamed: D32.2 (A), MX32.2
unnamed: D33.2 (A), MX33.2
unnamed: D34.2 (A), MX34.2
unnamed: D35.2 (A), MX35.2
unnamed: D36.2 (A), MX36.2
unnamed: D37.2 (A), MX37.2
unnamed: D38.2 (A), MX38.2
unnamed: D39.2 (A), MX39.2
unnamed: D40.2 (A), MX40.2
unnamed: D41.2 (A), MX41.2
unnamed: D42.2 (A), MX42.2
unnamed: D43.2 (A), MX43.2
unnamed: D44.2 (A), MX44.2
unnamed: D45.2 (A), MX45.2
unnamed: D46.2 (A), MX46.2
unnamed: D47.2 (A), MX47.2
unnamed: D48.2 (A), MX48.2
unnamed: D49.2 (A), MX49.2
unnamed: D50.2 (A), MX50.2
unnamed: D51.2 (A), MX51.2
unnamed: D52.2 (A), MX52.2
unnamed: D53.2 (A), MX53.2
unnamed: D54.2 (A), MX54.2
unnamed: D55.2 (A), MX55.2
unnamed: D56.2 (A), MX56.2
unnamed: D57.2 (A), MX57.2
unnamed: D58.2 (A), MX58.2
unnamed: D59.2 (A), MX59.2
unnamed: D60.2 (A), MX60.2
unnamed: D61.2 (A), MX61.2
unnamed: LED1.2 (DOUT), LED2.3 (DIN)
unnamed: LED2.2 (DOUT), LED3.3 (DIN)
unnamed: LED3.2 (DOUT), LED4.3 (DIN)
unnamed: LED4.2 (DOUT), LED5.3 (DIN)
unnamed: LED5.2 (DOUT), LED6.3 (DIN)
unnamed: LED7.2 (DOUT), LED8.3 (DIN)
unnamed: LED8.2 (DOUT), LED9.3 (DIN)
unnamed: LED9.2 (DOUT), LED10.3 (DIN)
unnamed: LED10.2 (DOUT), LED11.3 (DIN)
unnamed: LED11.2 (DOUT), LED12.3 (DIN)
unnamed: LED13.3 (DIN), LED14.2 (DOUT)
unnamed: LED13.2 (DOUT), LED25.3 (DIN)
unnamed: LED14.3 (DIN), LED15.2 (DOUT)
unnamed: LED15.3 (DIN), LED16.2 (DOUT)
unnamed: LED16.3 (DIN), LED17.2 (DOUT)
unnamed: LED17.3 (DIN), LED18.2 (DOUT)
unnamed: LED6.2 (DOUT), LED18.3 (DIN)
unnamed: LED19.3 (DIN), LED20.2 (DOUT)
unnamed: LED7.3 (DIN), LED19.2 (DOUT)
unnamed: LED20.3 (DIN), LED21.2 (DOUT)
unnamed: LED21.3 (DIN), LED22.2 (DOUT)
unnamed: LED22.3 (DIN), LED23.2 (DOUT)
unnamed: LED23.3 (DIN), LED24.2 (DOUT)
unnamed: LED24.3 (DIN), LED36.2 (DOUT)
unnamed: LED25.2 (DOUT), LED26.3 (DIN)
unnamed: LED26.2 (DOUT), LED27.3 (DIN)
unnamed: LED27.2 (DOUT), LED28.3 (DIN)
unnamed: LED28.2 (DOUT), LED29.3 (DIN)
unnamed: LED29.2 (DOUT), LED30.3 (DIN)
unnamed: LED30.2 (DOUT), LED42.3 (DIN)
unnamed: LED31.3 (DIN), LED43.2 (DOUT)
unnamed: LED31.2 (DOUT), LED32.3 (DIN)
unnamed: LED32.2 (DOUT), LED33.3 (DIN)
unnamed: LED33.2 (DOUT), LED34.3 (DIN)
unnamed: LED34.2 (DOUT), LED35.3 (DIN)
unnamed: LED35.2 (DOUT), LED36.3 (DIN)
unnamed: LED37.3 (DIN), LED38.2 (DOUT)
unnamed: LED37.2 (DOUT), LED50.3 (DIN)
unnamed: LED38.3 (DIN), LED39.2 (DOUT)
unnamed: LED39.3 (DIN), LED40.2 (DOUT)
unnamed: LED40.3 (DIN), LED41.2 (DOUT)
unnamed: LED41.3 (DIN), LED42.2 (DOUT)
unnamed: LED43.3 (DIN), LED44.2 (DOUT)
unnamed: LED44.3 (DIN), LED45.2 (DOUT)
unnamed: LED45.3 (DIN), LED46.2 (DOUT)
unnamed: LED46.3 (DIN), LED47.2 (DOUT)
unnamed: LED47.3 (DIN), LED48.2 (DOUT)
unnamed: LED48.3 (DIN), LED49.2 (DOUT)
unnamed: LED49.3 (DIN), LED61.2 (DOUT)
unnamed: LED50.2 (DOUT), LED51.3 (DIN)
unnamed: LED51.2 (DOUT), LED52.3 (DIN)
unnamed: LED52.2 (DOUT), LED53.3 (DIN)
unnamed: LED53.2 (DOUT), LED54.3 (DIN)
unnamed: LED54.2 (DOUT), LED55.3 (DIN)
unnamed: LED55.2 (DOUT), LED56.3 (DIN)
unnamed: LED56.2 (DOUT), LED57.3 (DIN)
unnamed: LED57.2 (DOUT), LED58.3 (DIN)
unnamed: LED58.2 (DOUT), LED59.3 (DIN)
unnamed: LED59.2 (DOUT), LED60.3 (DIN)
unnamed: LED60.2 (DOUT), LED61.3 (DIN)
unnamed: UG1.4 (DOUT), UG2.2 (DIN)
unnamed: UG2.4 (DOUT), UG3.2 (DIN)
unnamed: UG3.4 (DOUT), UG4.2 (DIN)
unnamed: UG4.4 (DOUT), UG5.2 (DIN)
unnamed: UG5.4 (DOUT), UG6.2 (DIN)
unnamed: UG6.4 (DOUT), UG7.2 (DIN)
unnamed: UG7.4 (DOUT), UG8.2 (DIN)
unnamed: UG8.4 (DOUT), UG9.2 (DIN)
unnamed: UG9.4 (DOUT), UG10.2 (DIN)
unnamed: UG10.4 (DOUT), UG11.2 (DIN)
unnamed: UG11.4 (DOUT), UG12.2 (DIN)
unnamed: UG12.4 (DOUT), UG13.2 (DIN)
unnamed: UG13.4 (DOUT), UG14.2 (DIN)
unnamed: UG14.4 (DOUT), UG15.2 (DIN)
unnamed: UG15.4 (DOUT), UG16.2 (DIN)
unnamed: UG16.4 (DOUT), UG17.2 (DIN)
unnamed: UG17.4 (DOUT), UG18.2 (DIN)
unnamed: UG18.4 (DOUT), UG19.2 (DIN)
unnamed: UG19.4 (DOUT), UG20.2 (DIN)
unnamed: UG20.4 (DOUT), UG21.2 (DIN)
unnamed: UG21.4 (DOUT), UG22.2 (DIN)
unnamed: UG22.4 (DOUT), UG23.2 (DIN)
unnamed: UG23.4 (DOUT), UG24.2 (DIN)
unnamed: UG24.4 (DOUT), UG25.2 (DIN)
unnamed: UG25.4 (DOUT), UG26.2 (DIN)
unnamed: UG26.4 (DOUT), UG27.2 (DIN)
unnamed: UG27.4 (DOUT), UG28.2 (DIN)
VCC: J2.9, LED1.1 (VDD), LED2.1 (VDD), LED3.1 (VDD), LED4.1 (VDD), LED5.1 (VDD), LED6.1 (VDD), LED7.1 (VDD), LED8.1 (VDD), LED9.1 (VDD), LED10.1 (VDD), LED11.1 (VDD), LED12.1 (VDD), LED13.1 (VDD), LED14.1 (VDD), LED15.1 (VDD), LED16.1 (VDD), LED17.1 (VDD), LED18.1 (VDD), LED19.1 (VDD), LED20.1 (VDD), LED21.1 (VDD), LED22.1 (VDD), LED23.1 (VDD), LED24.1 (VDD), LED25.1 (VDD), LED26.1 (VDD), LED27.1 (VDD), LED28.1 (VDD), LED29.1 (VDD), LED30.1 (VDD), LED31.1 (VDD), LED32.1 (VDD), LED33.1 (VDD), LED34.1 (VDD), LED35.1 (VDD), LED36.1 (VDD), LED37.1 (VDD), LED38.1 (VDD), LED39.1 (VDD), LED40.1 (VDD), LED41.1 (VDD), LED42.1 (VDD), LED43.1 (VDD), LED44.1 (VDD), LED45.1 (VDD), LED46.1 (VDD), LED47.1 (VDD), LED48.1 (VDD), LED49.1 (VDD), LED50.1 (VDD), LED51.1 (VDD), LED52.1 (VDD), LED53.1 (VDD), LED54.1 (VDD), LED55.1 (VDD), LED56.1 (VDD), LED57.1 (VDD), LED58.1 (VDD), LED59.1 (VDD), LED60.1 (VDD), LED61.1 (VDD), UG1.3 (VDD), UG2.3 (VDD), UG3.3 (VDD), UG4.3 (VDD), UG5.3 (VDD), UG6.3 (VDD), UG7.3 (VDD), UG8.3 (VDD), UG9.3 (VDD), UG10.3 (VDD), UG11.3 (VDD), UG12.3 (VDD), UG13.3 (VDD), UG14.3 (VDD), UG15.3 (VDD), UG16.3 (VDD), UG17.3 (VDD), UG18.3 (VDD), UG19.3 (VDD), UG20.3 (VDD), UG21.3 (VDD), UG22.3 (VDD), UG23.3 (VDD), UG24.3 (VDD), UG25.3 (VDD), UG26.3 (VDD), UG27.3 (VDD), UG28.3 (VDD)
col0: J1.2, MX1.1, MX13.1, MX25.1, MX37.1, MX49.1, MX50.1
col1: J1.3, MX2.1, MX14.1, MX26.1, MX38.1, MX51.1
col2: J1.4, MX3.1, MX15.1, MX27.1, MX39.1, MX52.1
col3: MX4.1, MX16.1, MX28.1, MX40.1, MX53.1
col4: J1.5, MX5.1, MX17.1, MX29.1, MX41.1, MX54.1
col5: J1.6, MX6.1, MX18.1, MX30.1, MX42.1, MX55.1
col6: J2.7, MX7.1, MX19.1, MX31.1, MX43.1, MX56.1
col7: J2.6, MX8.1, MX20.1, MX32.1, MX44.1, MX57.1
col8: J2.5, MX9.1, MX21.1, MX33.1, MX45.1, MX58.1
col9: J2.4, MX10.1, MX22.1, MX34.1, MX46.1, MX59.1
col10: J2.3, MX11.1, MX23.1, MX35.1, MX47.1, MX60.1
col11: J2.2, MX12.1, MX24.1, MX36.1, MX48.1, MX61.1
perkey-rgb: J1.1, LED1.3 (DIN)
row0: D1.1 (K), D2.1 (K), D3.1 (K), D4.1 (K), D5.1 (K), D6.1 (K), D7.1 (K), D8.1 (K), D9.1 (K), D10.1 (K), D11.1 (K), D12.1 (K), J1.7
row1: D13.1 (K), D14.1 (K), D15.1 (K), D16.1 (K), D17.1 (K), D18.1 (K), D19.1 (K), D20.1 (K), D21.1 (K), D22.1 (K), D23.1 (K), D24.1 (K), J1.8
row2: D25.1 (K), D26.1 (K), D27.1 (K), D28.1 (K), D29.1 (K), D30.1 (K), D31.1 (K), D32.1 (K), D33.1 (K), D34.1 (K), D35.1 (K), D36.1 (K), J1.9
row3: D37.1 (K), D38.1 (K), D39.1 (K), D40.1 (K), D41.1 (K), D42.1 (K), D43.1 (K), D44.1 (K), D45.1 (K), D46.1 (K), D47.1 (K), D48.1 (K), J1.10
row4: D50.1 (K), D51.1 (K), D52.1 (K), D53.1 (K), D54.1 (K), D55.1 (K), D56.1 (K), D57.1 (K), D58.1 (K), D59.1 (K), D60.1 (K), D61.1 (K), J1.11
row5: D49.1 (K), J2.8
underglow-rgb: J2.1, UG1.2 (DIN)

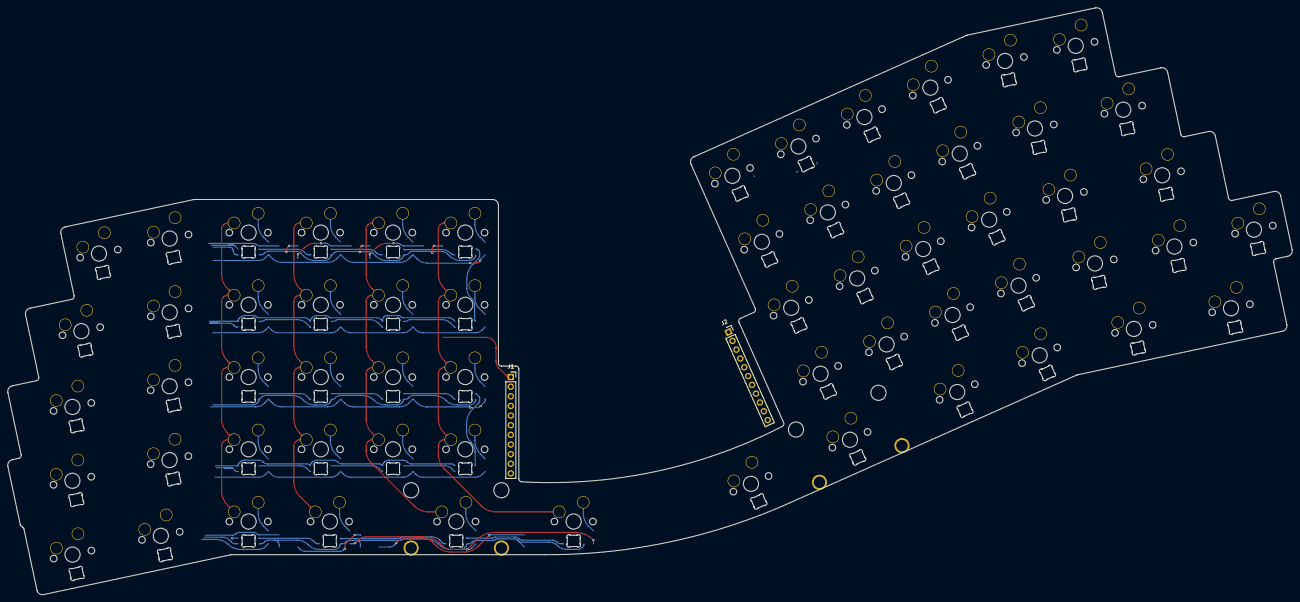
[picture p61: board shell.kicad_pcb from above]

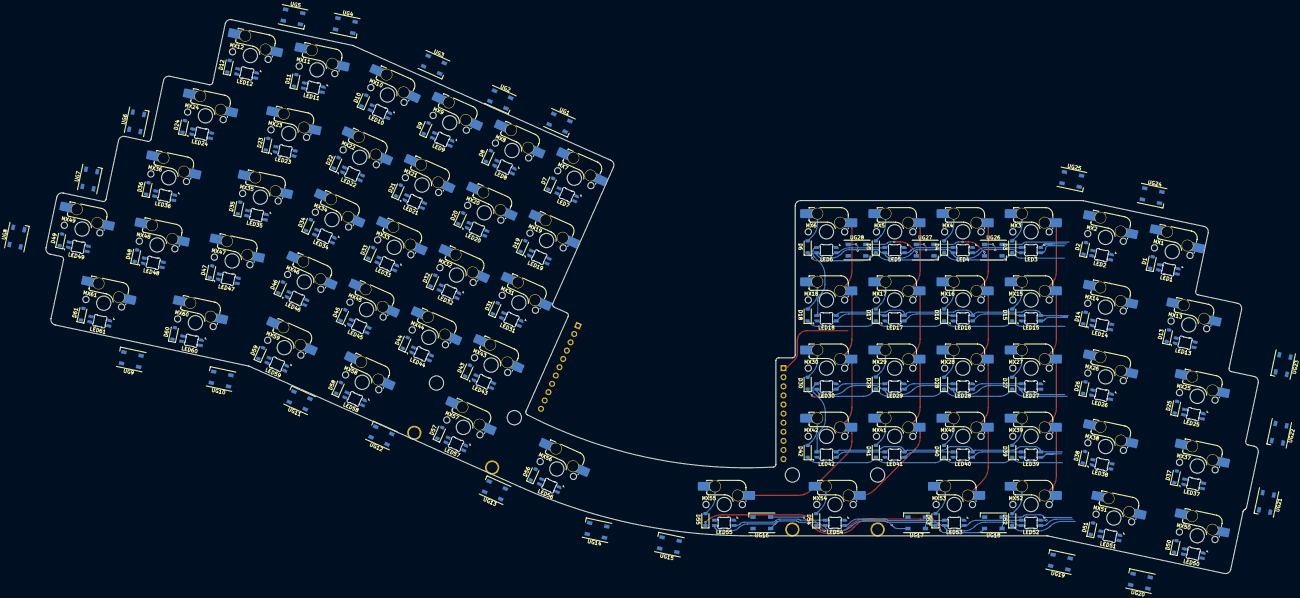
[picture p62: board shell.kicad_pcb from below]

Board: 2 copper layers, 338.7 x 154.8 mm, 215 parts (211 on the bottom side), 170 nets.

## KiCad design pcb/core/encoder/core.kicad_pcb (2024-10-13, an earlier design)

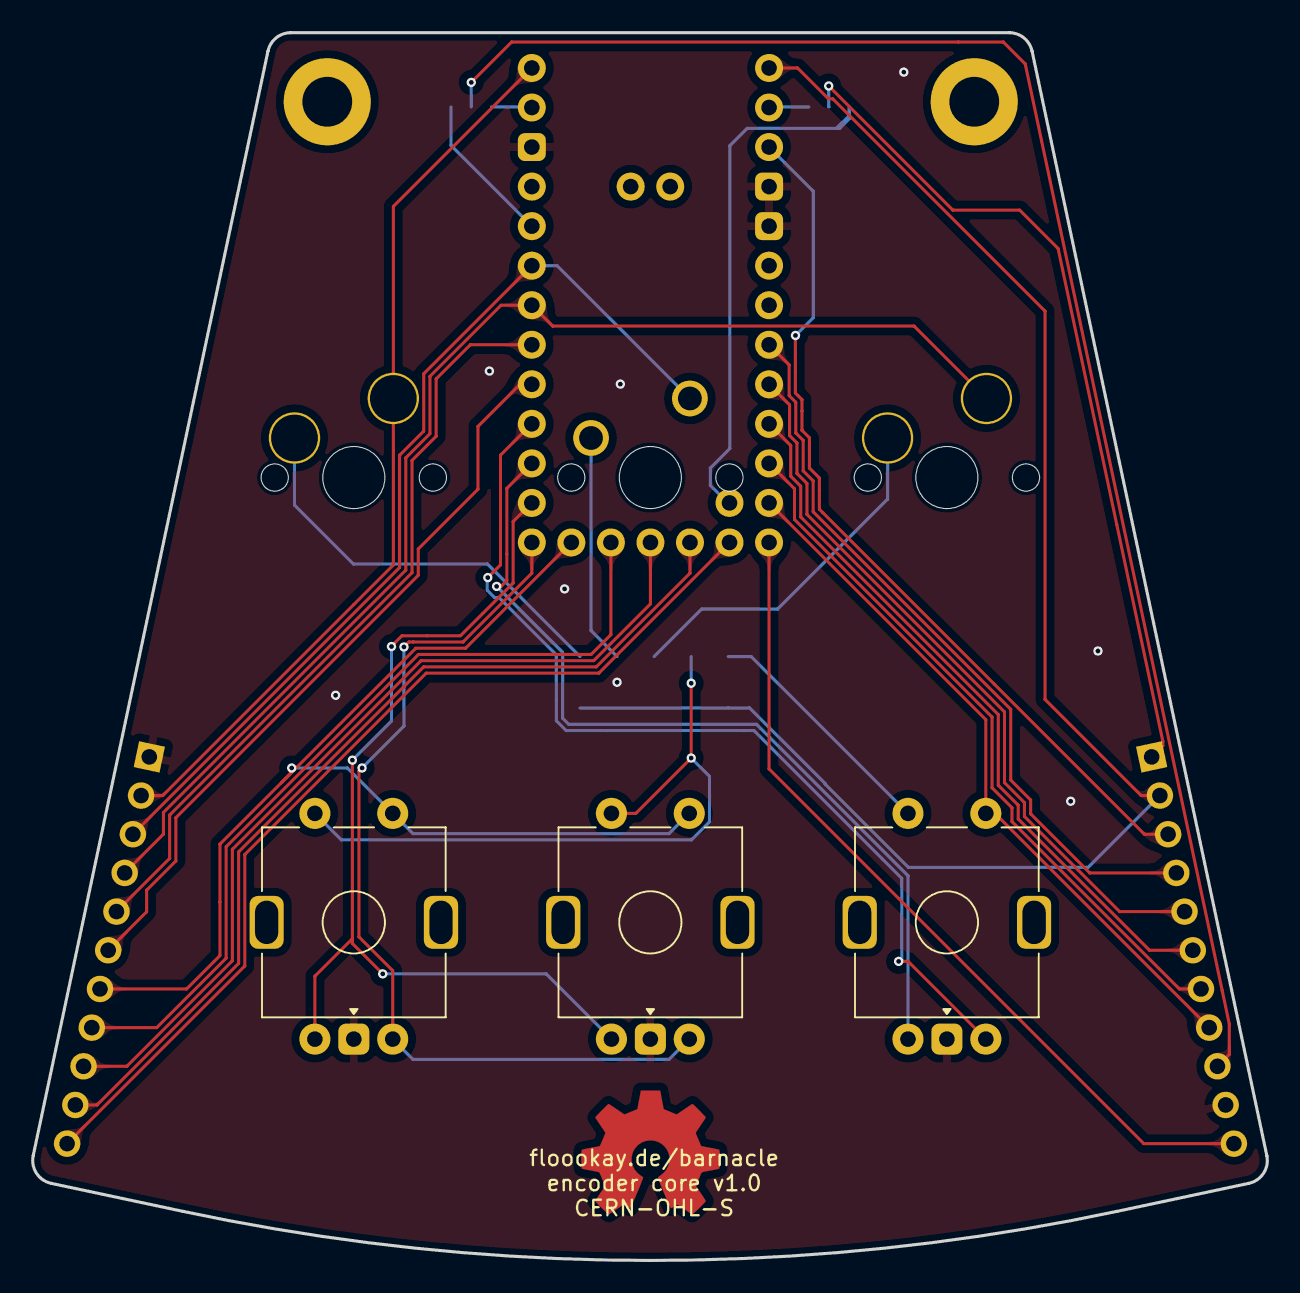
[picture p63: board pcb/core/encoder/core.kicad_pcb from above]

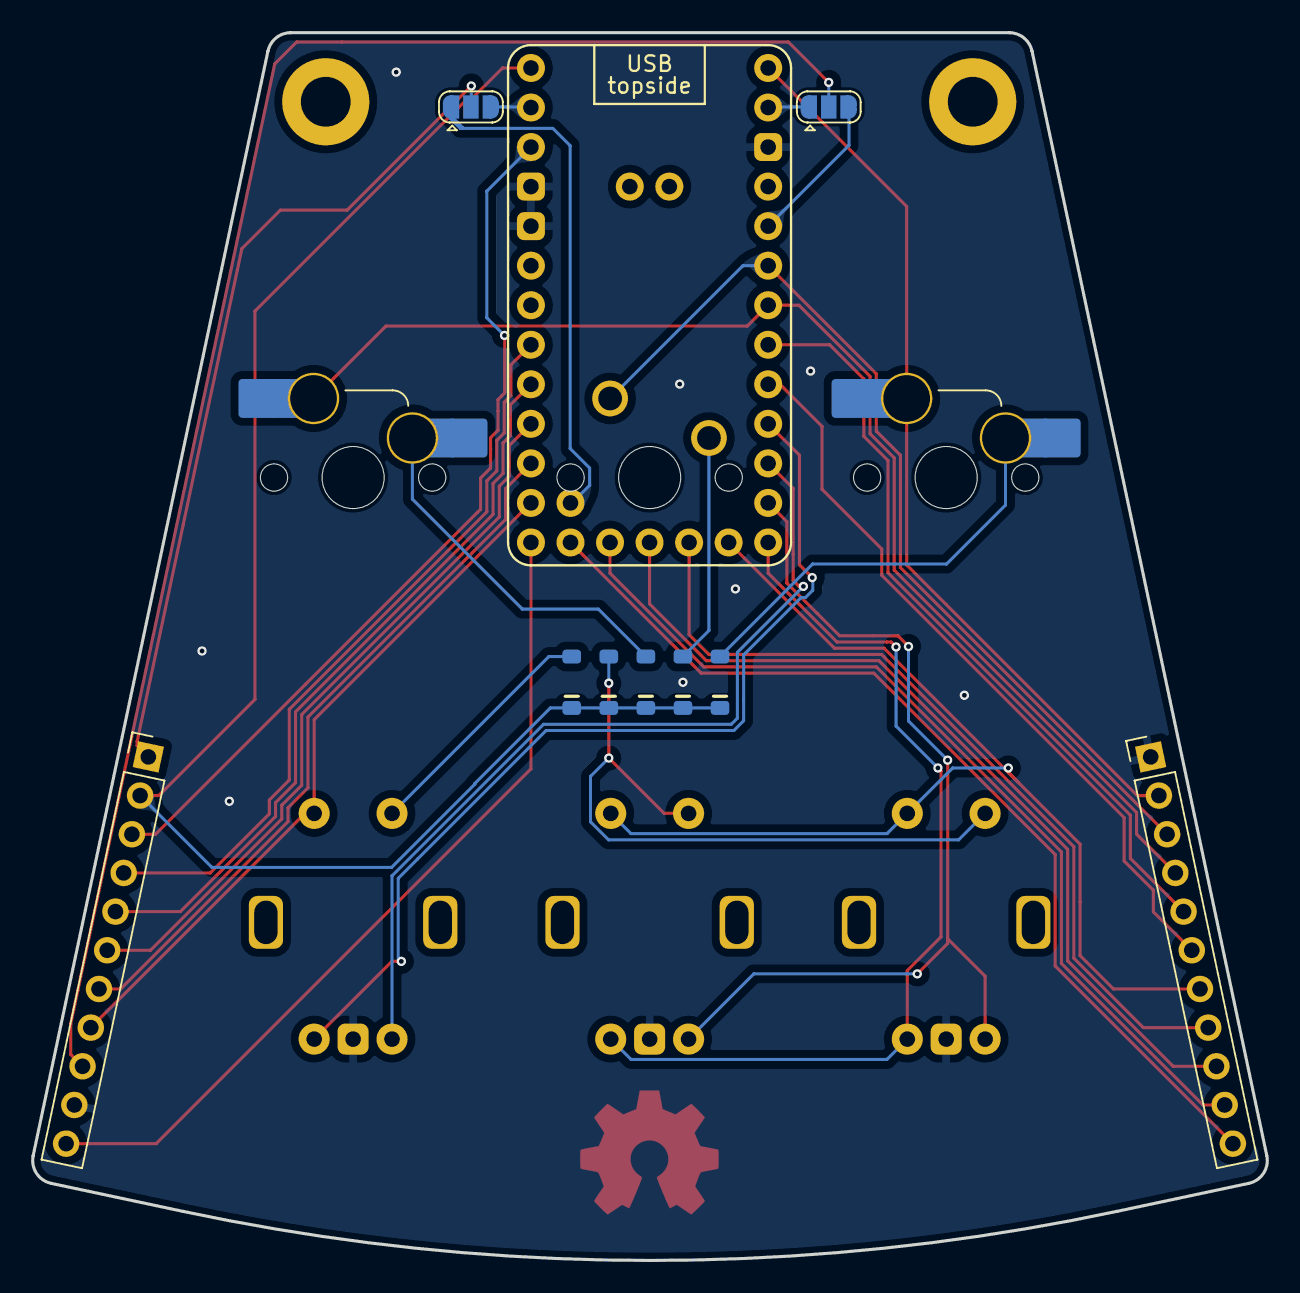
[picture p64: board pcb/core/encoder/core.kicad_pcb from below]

Board: 2 copper layers, 79.3 x 78.9 mm, 18 parts (12 on the bottom side), 34 nets.

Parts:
D1, D2, D3, D4, D10: D; D_SOD-123-minimal
H1, H2: MountingHole; MountingHole_3.2mm_M3_DIN965_Pad
J1, J2: Conn_01x11; PinHeader_1x11_P2.54mm_Vertical
JP3, JP4: Jumper_3_Open; SolderJumper-3_P1.3mm_Open_RoundedPad1.0x1.5mm
SW1, SW3: SW_Push_45deg; SW_MX_HS_S_CPG151101S11_1u
SW2: SW_Push_45deg; SW_MX_1u
SW4, SW5, SW11: RotaryEncoder_Switch; ROT_Alps_EC11E-Switch
U1: Helios; Helios_AH_USBup

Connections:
GND: J1.1, J2.10, SW4.C, SW5.C, SW11.C, U1.3 (GND), U1.4 (GND), U1.14 (GND)
unnamed: D1.2 (A), SW1.1
unnamed: D2.2 (A), SW2.1
unnamed: D3.2 (A), SW3.1
unnamed: D4.2 (A), SW5.S2
unnamed: D10.2 (A), SW4.S2, SW11.S2
unnamed: JP3.1 (A), U1.34 (P25)
unnamed: JP3.3 (B), U1.1 (P0)
unnamed: JP4.1 (A), U1.13 (5V)
col0: J1.2, SW1.2, U1.30 (P11)
col1: J1.3, SW2.2, U1.17 (P29)
col2: J1.4, SW3.2, U1.18 (P28)
col3: J1.5, U1.19 (P27)
col4: J1.6, U1.20 (P26)
col5: J1.7, SW4.S1, SW11.S1, U1.29 (P16)
col6: J2.8, SW5.S1, U1.11 (P8)
col7: J2.7, U1.10 (P7)
col8: J2.6, U1.9 (P6)
col9: J2.5, U1.8 (P5)
col10: J2.4, U1.7 (P4)
col11: J2.3, U1.2 (P1)
enc0: SW4.A, SW11.A, U1.23
enc1: SW4.B, SW11.B, U1.24 (P21)
enc2: SW5.B, U1.21 (P22)
enc3: SW5.A, U1.22 (P20)
rgb: J2.1, JP3.2 (C)
row0: J1.8, U1.28 (P15)
row1: J1.9, U1.27 (P14)
row2: J1.10, U1.26 (P13)
row3: J1.11, U1.25 (P12)
row4: J2.11, U1.12 (P9)
row5: D1.1 (K), D2.1 (K), D3.1 (K), D4.1 (K), D10.1 (K), J2.2, U1.31 (P10)
vcc: JP4.3 (B), U1.16 (3V3)
vccrgb: J2.9, JP4.2 (C)

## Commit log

2024-06-17 added prototyping files
    [plate_left_12.stl, plate_left_15.stl, plate_middle.stl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]
2024-06-17 added initial shell pcb files
    [left shell.kicad_pcb, left shell.kicad_sch, right shell.kicad_pcb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]
2024-06-17 added initial case design
    [barnacle-pcb-comments.dxf, barnacle-pcb.dxf, barnacle.FCStd]
2024-06-17 removed bad idea
    [left shell.kicad_pcb, left shell.kicad_sch, right shell.kicad_pcb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]
2024-06-24 backup from yesterday
    [barnacle.FCStd]
2024-06-24 backup updated bottom
    [barnacle.FCStd]
2024-06-25 finished plate and plate mounting
    [barnacle.FCStd]
2024-06-28 adjusted profile angle
    [barnacle.FCStd]
2024-06-28 added plate fixers
    [barnacle.FCStd]
2024-07-28 updated pcb edge cut
    [barnacle-pcb-old.dxf, shell.kicad_pcb, shell.kicad_sch]
2024-07-28 added core pcb and case chamfers+fillets
    [barnacle-pcb.dxf, barnacle.FCStd]
2024-08-11 added core case piece
    [barnacle.FCStd]
2024-08-11 added bottom plate (again)
    [barnacle.FCStd]
2024-08-11 updated screw holes
    [barnacle.FCStd]
2024-08-11 added 3x3 core
    [barnacle.FCStd]
2024-08-13 fixed per key rgb
    [shell.kicad_pcb, shell.kicad_sch]
2024-08-13 added underglow rgb
    [shell.kicad_pcb, shell.kicad_sch]
2024-08-13 started routing left side
    [shell.kicad_pcb]
2024-08-14 added a couple more traces on left side
    [shell.kicad_pcb]
2024-08-14 last commit before rework without rounded tracks
    because of a 100% crash rate when trying to generate the rounded tracks
    [barnacle-pcb-old.dxf, barnacle.FCStd, shell.kicad_sch]
2024-08-14 finished routing
    [shell.kicad_sch]
2024-08-16 added mounting holes
    [barnacle.FCStd, shell.kicad_sch]
2024-08-16 added core pcb template
    [barnacle-pcb-comments.dxf, barnacle-pcb.dxf, barnacle-pcb_core.dxf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]
2024-08-17 added two additional encoders
    [barnacle-bottom-plate.dxf, core.kicad_pcb, core.kicad_sch]
2024-08-17 finished pcbs
    [core.kicad_pcb, core.kicad_sch]
2024-08-17 added 3x1 encoder core
    [barnacle-case.3mf, barnacle-plate-fixation.3mf, barnacle-plate_left.3mf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]
2024-08-26 fixed bottom plate
    [barnacle-bottom-plate.dxf, barnacle-bottom_plate.dxf]
2024-08-30 added 1mm leeway between core case and pcb
    [barnacle.FCStd]
2024-08-31 added clamp for top plate fixer
    [barnacle.FCStd]
2024-08-31 updated files for 3d printing
    [barnacle-case.3mf, barnacle-case_core_3keys1knob.3mf, barnacle-plate-fixation.3mf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]
2024-09-01 added knob indentation
    [barnacle-case_core_3keys1knob.3mf, barnacle.FCStd]
2024-09-08 switched rgb back to a regular pin and 3v
    [barnacle-case_core_3keys1knob.3mf, barnacle.FCStd, core.kicad_pcb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]
2024-09-08 added alignment pins
    [barnacle-case.3mf, barnacle-case_core_3x3.3mf, barnacle.FCStd]
2024-09-08 added 2.25u core with 2 encoders
    [barnacle-case_core_2.25x1keys2knobs.3mf, barnacle.FCStd]
2024-09-09 fixed 2.25 grid spacing
    [barnacle-case_core_2.25x1keys2knobs.3mf, barnacle.FCStd]
2024-09-13 added jumpers for 3.3/5v rgb
    [core.kicad_pcb, core.kicad_sch]
2024-10-08 added 3x2 core case
    [barnacle-case_core_2x3.3mf, barnacle-case_core_3keys1knob.3mf, barnacle-case_core_3keys1knob_hole.3mf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]
2024-10-08 hid reference designators, simplified footprint silkscreens, added license, added rocks and stones
    [shell.kicad_sch]
2024-10-08 restructuring and splitting basic core freecad file
    [barnacle-basic_core.FCStd, barnacle-case_core_2.25x1keys2knobs.3mf, barnacle-case_core_2x3.3mf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]
2024-10-12 moved rgb jumpers to the other side
    [barnacle-extra_core.FCStd, barnacle-pcb_core_extra.dxf, core.kicad_pcb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]
2024-10-12 finished extra core pcb
    [core.kicad_pcb, core.kicad_sch]
2024-10-12 renamed core pcbs
    [barnacle-pcb_core_special.dxf, core.kicad_pcb, core.kicad_sch]
2024-10-12 added encoder core
    [core.kicad_pcb, core.kicad_sch]
2024-10-12 added versions
    [core.kicad_pcb]
2024-10-13 added numblock core pcb
    [core.kicad_pcb, core.kicad_sch]
2024-10-13 added cute core pcb (2x2)
    [core.kicad_pcb, core.kicad_sch]
2024-10-13 added wooden window case (wip)
    [barnacle-case_core_2.25x1keys2knobs.3mf, barnacle-case_core_2x3.3mf, barnacle-case_core_3keys1knob_hole.3mf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]
2024-10-13 generated fabrication files
    [bom.csv, core.kicad_pcb, designators.csv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]
2024-10-13 changed sk6812 footprints to be also compatible with sk6812 mini (v1.2)
    [bom.csv, designators.csv, positions.csv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]
2024-10-13 add script to correct rotation and added LCSC part numbers
    [bom.csv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]
2024-10-27 added tpu plate „foam“
    [barnacle-plate_tpu_left.3mf, barnacle-plate_tpu_right.3mf, barnacle.FCStd]
2024-10-27 added missing gnd vias
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2024-11-29 updated pcb to only use sk6812 mini-e
    [barnacle-case.3mf, barnacle-shell.3mf, bom.csv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]
2024-12-07 updated lcsc number
    [bom.csv]
2024-12-15 updated oled core to fit m2 screws
    [barnacle-case_core_oled.3mf, barnacle-versatile_core.FCStd]
2024-12-20 fixed rotation of top row underglow leds
    sigh…
    [positions.csv, shell.kicad_sch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]
2024-12-21 added middle piece for the cute core
    [barnacle-case_core_cute.3mf, barnacle-cute_core.FCStd]
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2024-12-25 added a comment on the plate file
    [plate_tester.scad]
2024-12-25 added a blank core case piece
    [barnacle-case-core_blank.3mf]
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2024-12-28 updated readme and added pictures
    [barnacle-case_core_2.25keys2knobs.3mf, barnacle-case_core_encoder.3mf]
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2025-02-08 added center knob core case
    [barnacle-case-center_knob.3mf]
2025-06-25 added printable „weight“
    has to be taped to the acryl
    [barnacle-weight.3mf, barnacle.FCStd]
2025-06-26 added a small cutout for the usb connector
    [barnacle-weight.3mf, barnacle.FCStd]
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2025-08-13 added break off key to the numpad core
    [barnacle-pcb_core_numpad.dxf, bom.csv, core.kicad_pcb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]
2025-08-13 fixed directory name
    [barnacle-pcb_core_numpad.dxf, bom.csv, core.kicad_pcb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]
2025-08-13 fixed name on pcb
    [core.kicad_pcb]

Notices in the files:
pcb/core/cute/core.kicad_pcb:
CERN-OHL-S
